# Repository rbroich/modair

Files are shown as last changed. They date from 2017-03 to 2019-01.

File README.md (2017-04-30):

# ModAir
Modular Aviation Instruments - Open Source Avionics for Microlights and other Non-Type-Certified Aircraft

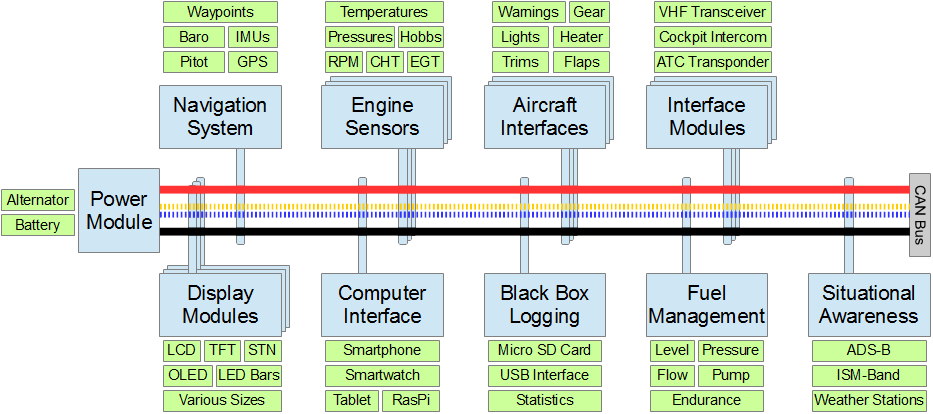
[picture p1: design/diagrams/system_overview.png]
System Overview


For documentation and details refer to the Hackaday.io Project Page [ModAir - Modular Aviation Instruments](https://hackaday.io/project/19325)

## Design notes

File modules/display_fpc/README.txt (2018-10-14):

ERC240160_ENCLOSURE

rotary encoder: solder ribbon cable
(mounted to PCB would have insufficient reach, and mechanically difficult to insert with the LCD FPC soldered on already)

add SPDT switch on left side
and LED?

Fine grid sand paper on top
Printed front panel labels on thick transparency (guerrilla glass?)
-black portions to cover 3d printed inconsistencies

PCB:
-no components on bottom side, besides BUS connector
-header for LCD backlight
-LCD FPC footprint directly below LCD, inline with edge of LCD frame
-header for rotary encoder
-solder pads for switch
-electrolytic caps mounted sideways

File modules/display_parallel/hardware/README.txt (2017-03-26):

Different Configurations:

Option 1: 5.8" WITSCHI_ERM25664AAG-1 EastRising 256x64 pixel graphic LCD module Blue backlight.
-LCD goes on top of PCB
-Headers row on the left aligns
-Mounting holes on the left align
-Top right mounting hole aligns with frame ground pad on LCD (solder spacer?)
-Electrolytic Caps C4 and C5 can be bent over
-Contrast Potentiometer not needed (already on LCD module)
-Rot Encoder header attached to Bottom
-LED (or header?) soldered on Bottom
-Screw Terminals attached to Bottom

Option 2: 2.9" NelyTech NT-G128641A 128x64 Graphic LCD Display Module 2xKS0108 Black on White.
-LCD goes on top of PCB
-Headers row on the bottom aligns
-All mounting holes align
-Bend electrolytic caps C4 and C5 over
-Contrast Potentiometer soldered
-Rot Encoder header attached to Bottom
-LED (or header?) soldered on Bottom
-Screw Terminals attached to Bottom

Option 3: 3.1" Generic 5V 12864B V2.0 LCD Display Module 128x64 Dots Graphic Matrix LCD Blue Backlight
-Identical mounting to Option 2
-CS1 becomes PSB [parallel mode] (ST7920, 2MHz clock rate)
-CS2 is not used
-Contrast Potentiometer not needed (already on LCD module)
-Backlight Resistor already on LCD module. Drive with 5V

Option 4: Generic HD44780 2x16 Character LCD Blue Backlight
-Cut PCB Smaller
-LCD goes on top of PCB, rotated 180 degrees
-Headers row on the bottom right aligns
-All mounting holes align
-Rot Encoder mounts vertically on top left PCB (isolate exposed header pins underneath...gnd plate on bottom of rotenc)
-LED mounts vertically on top right
-Electrolytic caps C4 and C5 mount vertically
-Screw Terminals attached to Bottom

ASSEMBLY:
Option 2 & 3:
-3D printed mounting hole standoffs with outer rectangle
-11mm Standoffs (distance between LCD and PCB)
-Male headers on LCD
-Female headers on PCB
-1.6mm PCBs

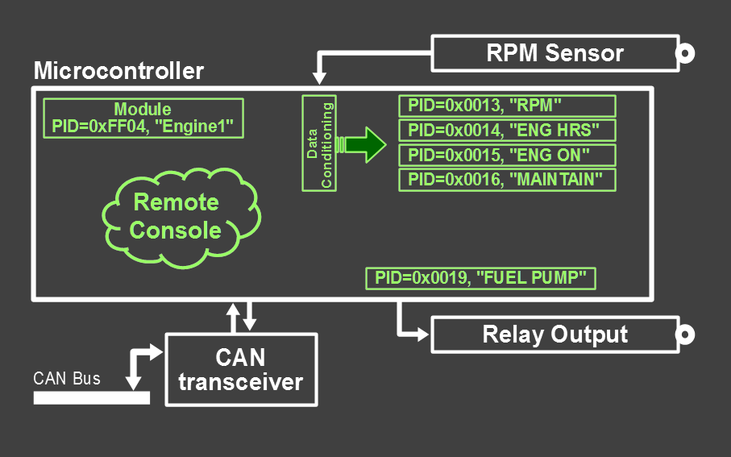
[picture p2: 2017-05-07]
design/diagrams/module_overview_white.png

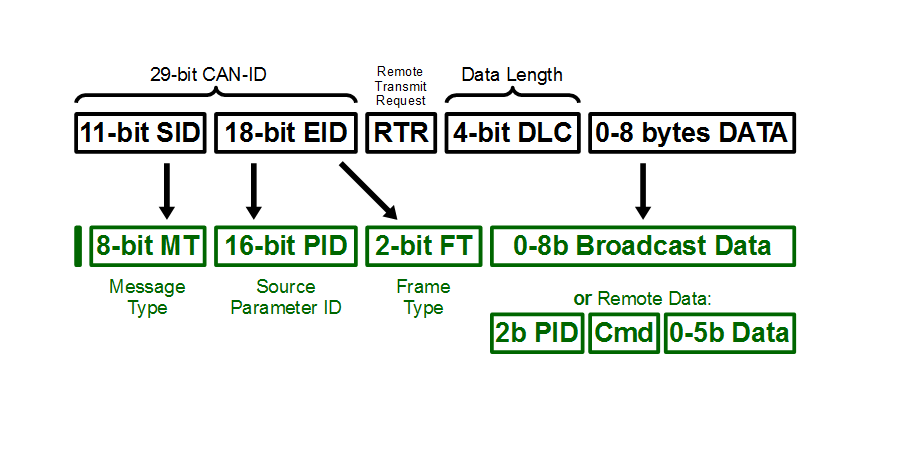
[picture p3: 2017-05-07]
design/diagrams/can_id_format_black.png

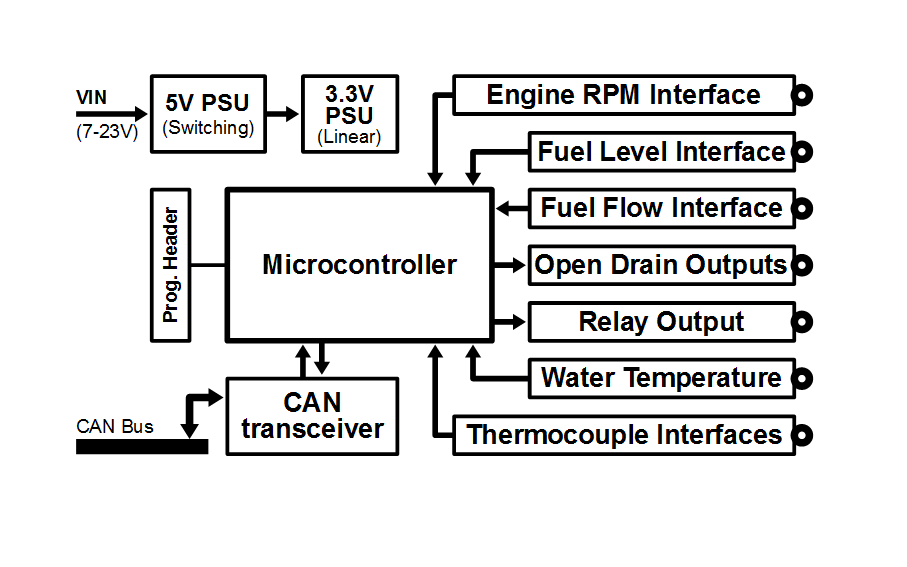
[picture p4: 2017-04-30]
design/diagrams/rotax_engine_module_black.png

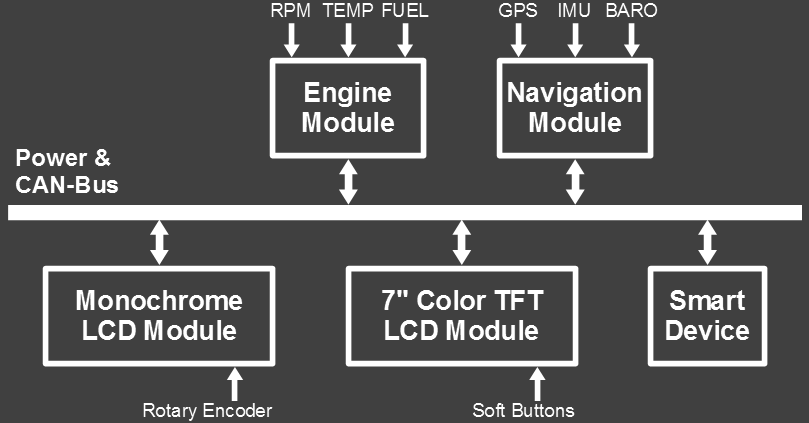
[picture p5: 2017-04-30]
design/diagrams/simple_block_diagram_white.png

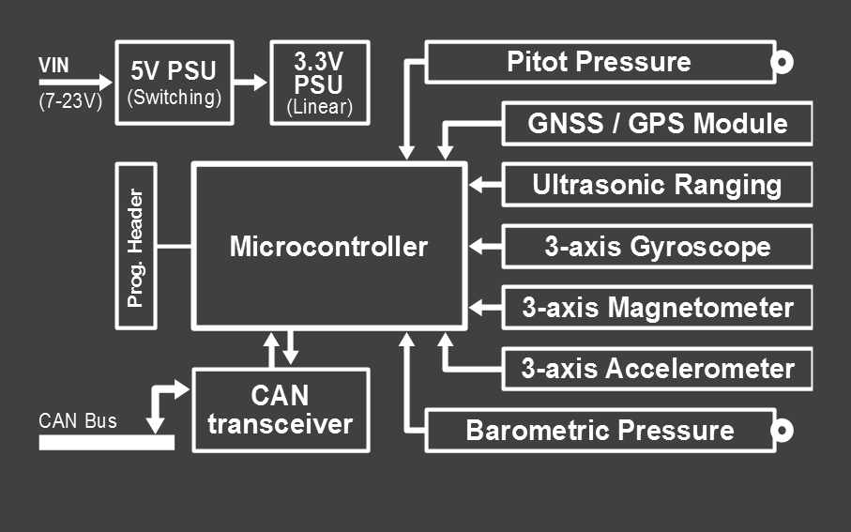
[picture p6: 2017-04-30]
design/diagrams/navigation_module_white.png

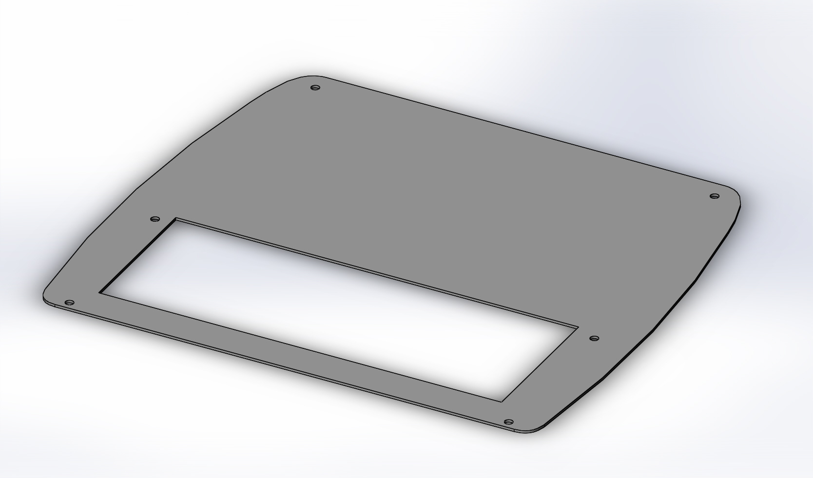
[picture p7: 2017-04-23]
modules/display_parallel/mechanical/solidworks_frontpanel/erm25664_frontpanel.JPG

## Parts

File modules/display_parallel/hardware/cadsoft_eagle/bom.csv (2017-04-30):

Qty | Value | Device | Package | Parts | Description | MF | MPN | OC_FARNELL | OC_NEWARK
1 |  | LED-FKIT-1206 | FKIT-LED-1206 | PWR | LEDs
1 |  | LED5MM | LED5MM | LED1 | LED
1 |  | M05PTH | 1X05 | JP1 | Header 5
1 |  | MA04-1 | MA04-1 | ROT_ENC | PIN HEADER |  |  | unknown | unknown
2 |  | MOSFET-NREFLOW | SOT23 | Q1, Q3 | N-Channel Mosfet
1 |  | TRIM_EU-B64Y | B64Y | R1 | POTENTIOMETER
1 | 0R-JUMPB | 0R-JUMPB | B0R-JMP | JMP1 | SMD 0R 0805 Jumper
2 | 100n | C-EUC0603K | C0603K | C6, C7 | CAPACITOR, European symbol
1 | 100u | CPOL-EUE2.5-7 | E2,5-7 | C4 | POLARIZED CAPACITOR, European symbol
3 | 10k | R-EU_R0603 | R0603 | R7, R11, R16 | RESISTOR, European symbol
1 | 10u | C-EU025-030X050 | C025-030X050 | C10 | CAPACITOR, European symbol
1 | 120 | R-EU_R0603 | R0603 | R21 | RESISTOR, European symbol
3 | 150 | R-EU_R0603 | R0603 | R2, R3, R4 | RESISTOR, European symbol
1 | 1N4004 | 1N4004 | DO41-10 | D1 | DIODE
4 | 1u | C-EUC0603K | C0603K | C1, C2, C3, C9 | CAPACITOR, European symbol
3 | 33n | C-EUC0603K | C0603K | C11, C12, C13 | CAPACITOR, European symbol
1 | 470u | CPOL-EUE3.5-8 | E3,5-8 | C5 | POLARIZED CAPACITOR, European symbol
1 | AMS1117 | LD117AS33TR | SOT223 | IC5 | Low drop fixed and adjustable positive voltage regulators 1 A
1 | DSPIC33EP512GP502-I/SP | DSPIC33EP512GP502-I/SP | DIL28-3 | IC1 | 16-Bit Microcontrollers and Digital Signal Controllers
1 | EASTRISING_12864-2 | EASTRISING_12864-2 | 1X20 | G12864 | 2.9128x64 Graphic LCD Display Module KS0108 Black on White."
1 | F/QMX | F/QMX | F/QMX | BUZZ | BUZZER Source: Buerklin |  |  | unknown | unknown
1 | GENERIC_16X02_LCD | GENERIC_16X02_LCD | 1X16 | C1602
1 | MCP2562 | MCP2562-E/P | DIL8 | IC3 | High-Speed CAN Transceiver
1 | MINI_DC_DC_CONVSMD | MINI_DC_DC_CONVSMD | DSN-MINI-360-SMD | U$1 | RC Airplane Module Mini 360 DC Buck Converter Step Down Module 4.75V-23V to 1V-17V 17x11x3.8mm New LM2596;
1 | ROTARTY_ENCODER | ROTARTY_ENCODER | ROTARY_ENC_PLAIN | SW1 | Simple no LED rotary encoder
1 | WITSCHI_ERM25664AAG-1 | WITSCHI_ERM25664AAG-1 | 1X20 | GLCD_ERM | EastRising 256x64 pixel graphic LCD module
2 | XY301V-A | XY301V-A | XY301V-A | CN1, CN2 | 3 Pin Screw Terminal Block Connector 5mm Pitch 5.08-301-3P 301-3P 3pin

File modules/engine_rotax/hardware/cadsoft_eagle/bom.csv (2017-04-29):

Qty | Value | Device | Package | Parts | Description | MF | MPN | OC_FARNELL | OC_NEWARK | PROD_ID | VALUE
1 |  | DIODESMA | SMADIODE | D1 | Diode
2 |  | LED-FKIT-1206 | FKIT-LED-1206 | 3.3V_PWR, LED | LEDs
5 |  | M01PTH_LONGPAD | 1X01_LONGPAD | COM, NC, NO, OD1, OD2 | Header 1
1 |  | M05PTH | 1X05 | JP1 | Header 5
1 |  | MOSFET-NREFLOW | SOT23 | Q1 | N-Channel Mosfet
1 | 1000u | CPOL-EUE3.5-8 | E3,5-8 | C5 | POLARIZED CAPACITOR, European symbol
1 | 100k | R-EU_R0603 | R0603 | R18 | RESISTOR, European symbol
2 | 100n | C-EUC0603K | C0603K | C4, C7 | CAPACITOR, European symbol
1 | 100u | CPOL-EUE2.5-7 | E2,5-7 | C3 | POLARIZED CAPACITOR, European symbol
1 | 10k | R-EU_R0603 | R0603 | R11 | RESISTOR, European symbol
1 | 10u | C-EUC3225 | C3225 | C6 | CAPACITOR, European symbol
2 | 120 | R-EU_R0603 | R0603 | R9, R21 | RESISTOR, European symbol
2 | 150 | R-EU_R0603 | R0603 | R1, R4 | RESISTOR, European symbol
8 | 1k | R-EU_R0603 | R0603 | R3, R7, R8, R10, R12, R13, R14, R17 | RESISTOR, European symbol
1 | 1k5 | R-EU_R0603 | R0603 | R6 | RESISTOR, European symbol
1 | 1u | C-EUC0603 | C0603 | C9 | CAPACITOR, European symbol
2 | 1u | C-EUC0603K | C0603K | C1, C2 | CAPACITOR, European symbol
1 | 200k | R-EU_R0603 | R0603 | R19 | RESISTOR, European symbol
2 | 22k | R-EU_R0603 | R0603 | R2, R5 | RESISTOR, European symbol
1 | 2n7002 | MOSFET-NREFLOW | SOT23 | Q3 | N-Channel Mosfet
1 | AMS1117-3.3 | LD117AS33TR | SOT223 | IC5 | Low drop fixed and adjustable positive voltage regulators 1 A
1 | DSPIC33EP32GP502-I/SO | DSPIC33EP32GP502-I/SO | SO28W | IC2 | 16-Bit Microcontrollers and Digital Signal Controllers
1 | IRF540N | MOSFET-NGDS_TO220V | TO220V | Q2 | N-Channel Mosfet
1 | JQC-3FF-12 | G5L | G5LE | K1 | RELAY |  |  | unknown | unknown
8 | LSP10 | LSP10 | LSP10 | 0V, 3.3V, 5.0V, GND, IO1, IO2, IO3, IO4 | SOLDER PAD drill 1.0 mm, distributor Buerklin, 12H555
2 | MAX6675 | MAX6675 | SO08 | IC1, IC4 | Cold-Junction-Compensated K-Thermocouple-to-Digital Converter
1 | MCP2562-E/P | MCP2562-E/P | DIL8 | IC3 | High-Speed CAN Transceiver
1 | MINI_DC_DC_CONVSMD | MINI_DC_DC_CONVSMD | DSN-MINI-360-SMD | U$1 | RC Airplane Module Mini 360 DC Buck Converter Step Down Module 4.75V-23V to 1V-17V 17x11x3.8mm New LM2596;
13 | N/A | R-EU_R0603 | R0603 | R15, R16, R20, R23, R24, R25, R26, R29, R30, R31, R32, R35, R36 | RESISTOR, European symbol
2 | PMEG4005EJ | DIODE-SCHOTTKY-PMEG4005EJ | SOD-323 | D2, D5 | Schottky diodes in SFE's production catalog |  |  |  |  | DIO-10955 | PMEG4005EJ
4 | XY301V-A | XY301V-A | XY301V-A | CN1, CN2, CN3, CN4 | 3 Pin Screw Terminal Block Connector 5mm Pitch 5.08-301-3P 301-3P 3pin
1 | Zener 3.3V | DIODE-ZENERMM | MINIMELF | Z2 | Zener Diode

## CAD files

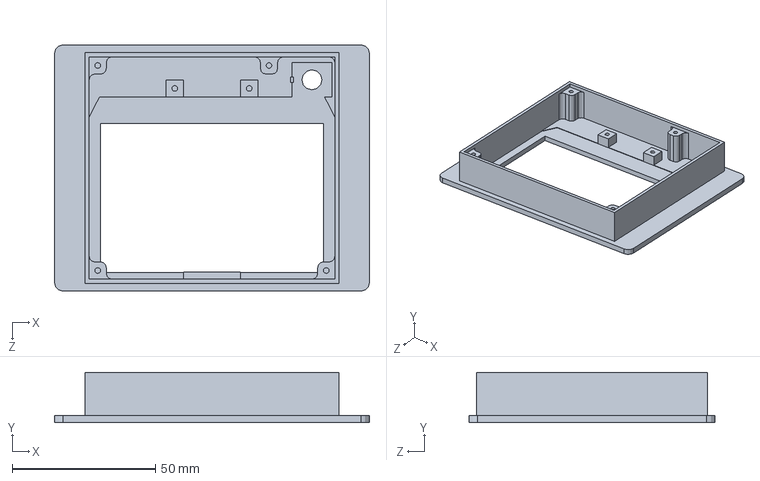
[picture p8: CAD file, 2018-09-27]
modules/display_fpc/mechanical/solidworks_enclosure/ERC240160_ENCLOSURE.SLDPRT
110.0 x 17.5 x 86.0 mm

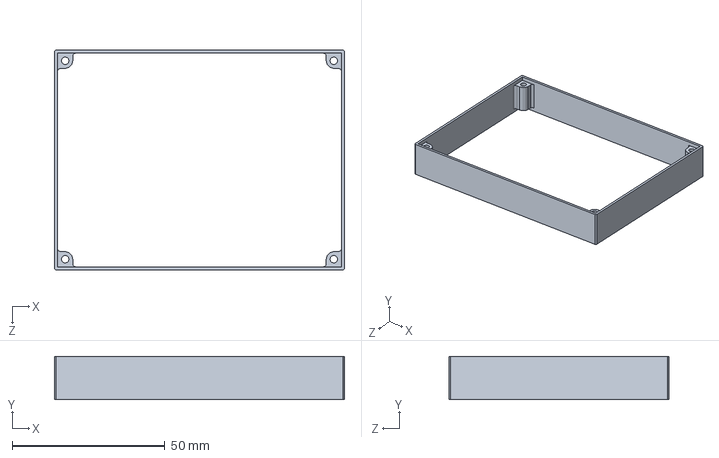
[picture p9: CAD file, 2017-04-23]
modules/display_parallel/mechanical/solidworks_brackets/g12864b_bracket.SLDPRT
95.0 x 14.2 x 72.0 mm

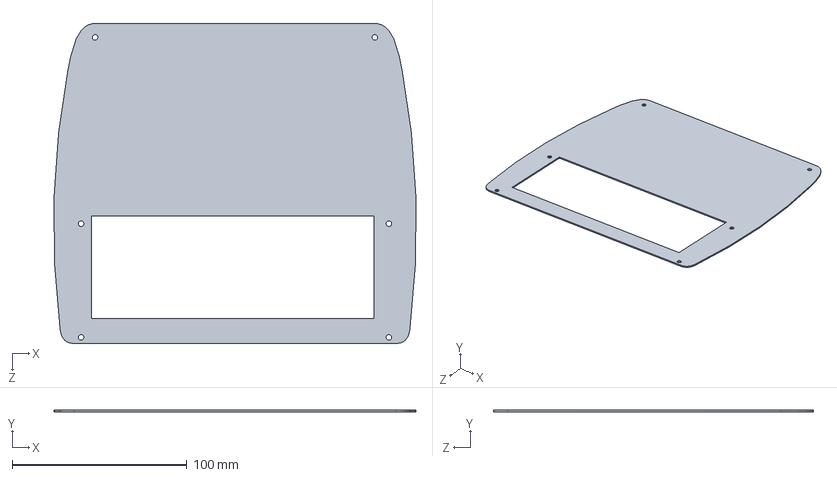
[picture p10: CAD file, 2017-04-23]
modules/display_parallel/mechanical/solidworks_frontpanel/erm25664_frontpanel.SLDPRT
207.0 x 1.00 x 183.0 mm

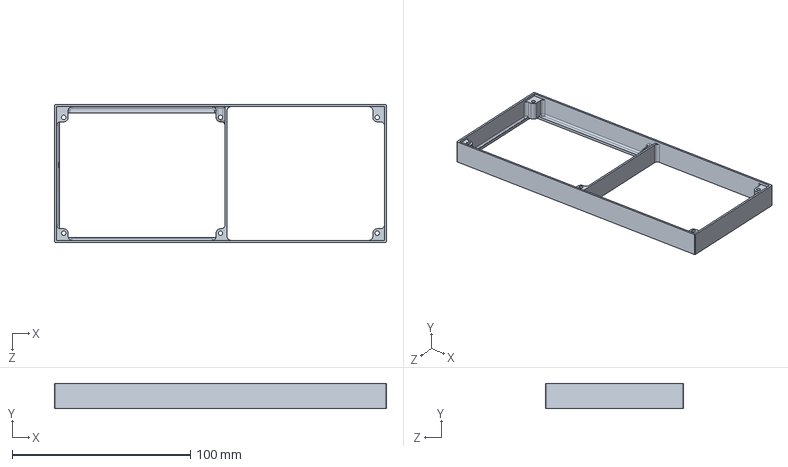
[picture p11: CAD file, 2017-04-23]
modules/display_parallel/mechanical/solidworks_brackets/erm25664_bracket.SLDPRT
186.4 x 14.2 x 77.4 mm

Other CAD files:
modules/display_fpc/mechanical/solidworks_enclosure/ERC240160_ENCLOSURE.SLDDRW
modules/display_fpc/mechanical/solidworks_enclosure/ERC240160_ENCLOSURE.STL
modules/display_parallel/mechanical/solidworks_brackets/erm25664_bracket.STL
modules/display_parallel/mechanical/solidworks_brackets/g12864b_bracket.STL
modules/display_parallel/mechanical/solidworks_frontpanel/erm25664_frontpanel.DXF

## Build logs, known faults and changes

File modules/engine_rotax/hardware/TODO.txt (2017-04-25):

change CAN transceiver to SMD

cable mounting? move screw terminals closer to edge of box, and shorten PCB on that side.
Ensure no THP and ideally no top-layer routes between screw terminal and edge of PCB. Add holes for cable tie to hold down cables?

add capacitor from RPM_IRQ to GND?

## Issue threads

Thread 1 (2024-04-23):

The status of the project is developing | abandoned

brightproject, 2024-04-23:
Good afternoon @rbroich
Your project is interesting, are you still developing it?
How are things going with the ACRS? Have you tried it in real flights?
If you are interested, you can chat.

rbroich, 2024-04-23:
Hello,
Thank you for your interest in this project. Yes, I actively used it for quite a while until I sold the plane and moved to another country. Unfortunately this also means that the project is abandoned now. You can find a write-up of the concepts on hackaday.
Kind regards

brightproject, 2024-04-23:
> Hello, Thank you for your interest in this project. Yes, I actively used it for quite a while until I sold the plane and moved to another country. Unfortunately this also means that the project is abandoned now. You can find a write-up of the concepts on hackaday. Kind regards

Yes, I read the concept on `hackaday`.
From the code in the repository * I didn’t quite understand, did you get the orientation angles (roll, heading and yaw) from the `MEMS` gyroscope and accelerometer sensor?
As I understand it, the navigation module received data from `MEMS` sensors and transmitted them via the `CAN` bus to another microcontroller, which in turn displayed attitude indicator information on the display.

> https://github.com/rbroich/modair/blob/master/modules/display_parallel/firmware/dspic_ntg128641a/widgets.c

Or your device did not display a picture of the attitude indicator, but only this data:
```
        // compass with GPS heading
        draw_compass(31,31,pid_vals[17].val);

        // fuel level: text
        LCD_string((char*)"Fuel ", 0, 117, font_sml2);
        ptr = mprint_float(tmp_str, pid_vals[7].val, 2, 2); // 48.63l
        strcpy(ptr,"l");
        LCD_string(tmp_str, LCD_X-6*4, 117, font_sml2);

        // fuel level: bottom hbar
        draw_hbar(0,123,64,5,pid_vals[7].val*100.0/50.0);

        // bus voltage: bottom right
        ptr = mprint_float(tmp_str, pid_vals[0].val, 2, 1); // xx.xV
        strcpy(ptr,"V");
        LCD_string(tmp_str, 0, 111, font_sml2);

        // h20 temp: bottom left (1 line up)
        ptr = mprint_float(tmp_str, pid_vals[8].val, 2, 1); // xx.x
        strcpy(ptr," C");
        LCD_string(tmp_str, LCD_X-24, 110, font_sml2);
        lcd_setpixel(LCD_X-6,110,LCD_BLACK); // degrees dot

        // Altitude
        ptr = mprint_float(tmp_str, pid_vals[19].val, 4, 0); // 5560 ft
        strcpy(ptr," ft");
        LCD_string(tmp_str, 32-3.5*6, 65, font_def);

        // Velocity
        ptr = mprint_float(tmp_str, pid_vals[18].val, 2, 0); // 54 mph
        strcpy(ptr," mph");
        LCD_string(tmp_str, 32-3*6, 65+9, font_def);

        // RPM
        ptr = mprint_float(tmp_str, pid_vals[3].val, 4, 0); // 2240 rpm
        strcpy(ptr," RPM");
        LCD_string(tmp_str, 31-4*4, 88, font_sml1);
        LCD_line(4,95,LCD_X-1-4,95,LCD_BLACK);
        u8 rpm_ratio = pid_vals[3].val*(LCD_X-8)/8000.0;
        LCD_line(4+rpm_ratio,97,4+rpm_ratio,94,LCD_BLACK);
        LCD_line(3+rpm_ratio,97,3+rpm_ratio,94,LCD_BLACK);

        // engine on time: bottom left (2 lines up)
        ptr = mprint_float(tmp_str, pid_vals[5].val*60.0, 3, 0); // 012m
        strcpy(ptr,"m");
        LCD_string(tmp_str, 0, 104, font_sml2);

        // Time in UTC
        u8 *fl_ptr;
        fl_ptr = (u8*)&pid_vals[20].val;
        ptr = mprint_int(tmp_str, fl_ptr[2], 10, 2); // 06:54
        *ptr++ = ':';
        mprint_int(ptr, fl_ptr[1], 10, 2);
        LCD_string(tmp_str, LCD_X-5*4, 104, GLCD_ROTATE_0,GLCD_FONT_3x5,LCD_BLACK,5);
```
Why was MPU6050 used in the project?

> https://github.com/rbroich/modair/blob/d1b8abdae54bf87aca975da74885fdfdacb7dc6f/modules/navigation/firmware/dspic_nav/mpu6050_driv.c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

Do you have any photos of the display with the menu and in operation?
I'm interested in understanding your code and rewriting it for `STM32` for a color display.

brightproject, 2024-12-02:
Good day @rbroich 🙂
Unfortunately, you don't answer often, apparently you have little time for your hobby and this project.
I would like to ask you one more question, in this project

> https://hackaday.io/project/21327-modair-navigation-module

you indicated that it is possible to implement the following Features in the module:

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

When studying the code, I did not find a block for determining the vertical speed.
Could you tell me how you implemented or not the measurement of `vertical speed`?

You also wrote that you plan to return to the project, I would be interested in your return, because I am curious about your implementation of the exchange protocol based on the `CAN` bus. However, I do not quite understand its implementation and why you did not start using generally accepted `CAN ID` numbers, such as, for example, the `ARINC 825` standard for `CANaerospace`?

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

[can_as.zip](https://github.com/user-attachments/files/17982959/can_as.zip)

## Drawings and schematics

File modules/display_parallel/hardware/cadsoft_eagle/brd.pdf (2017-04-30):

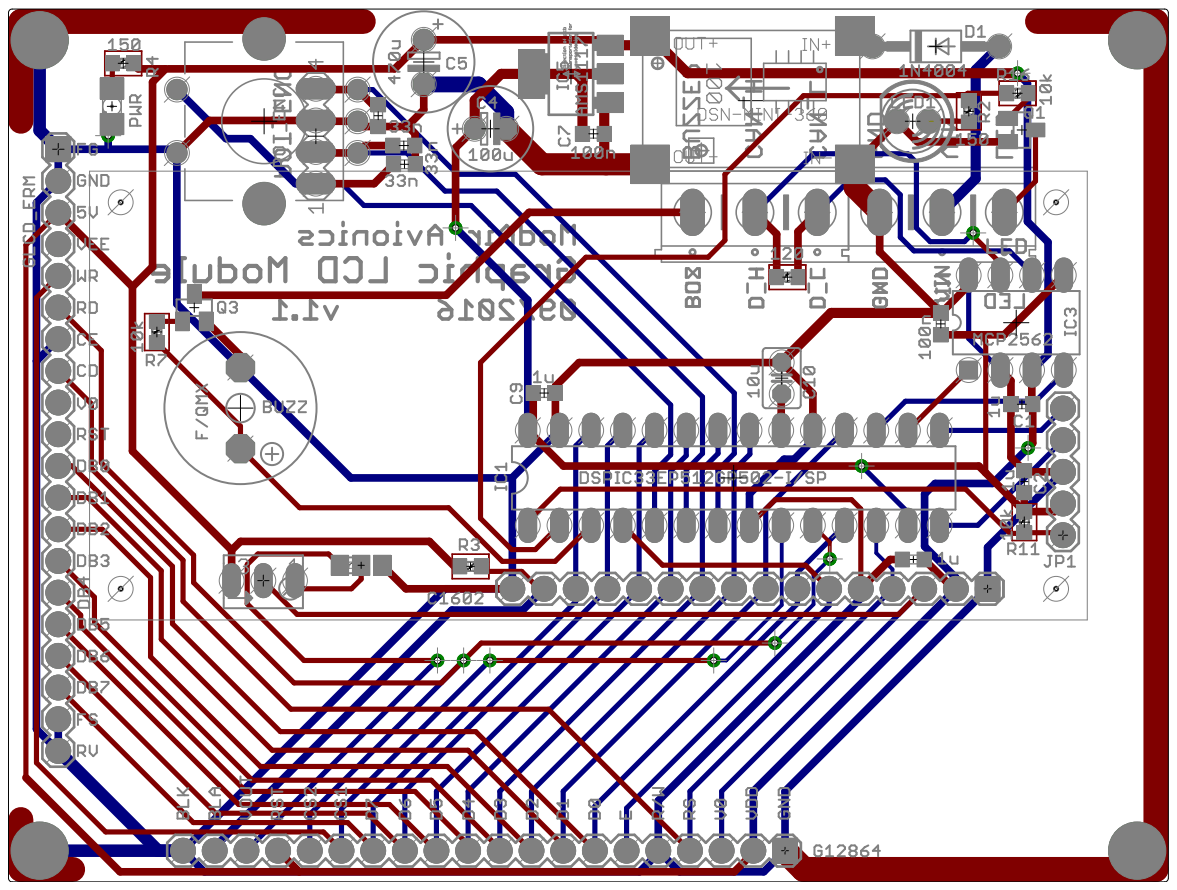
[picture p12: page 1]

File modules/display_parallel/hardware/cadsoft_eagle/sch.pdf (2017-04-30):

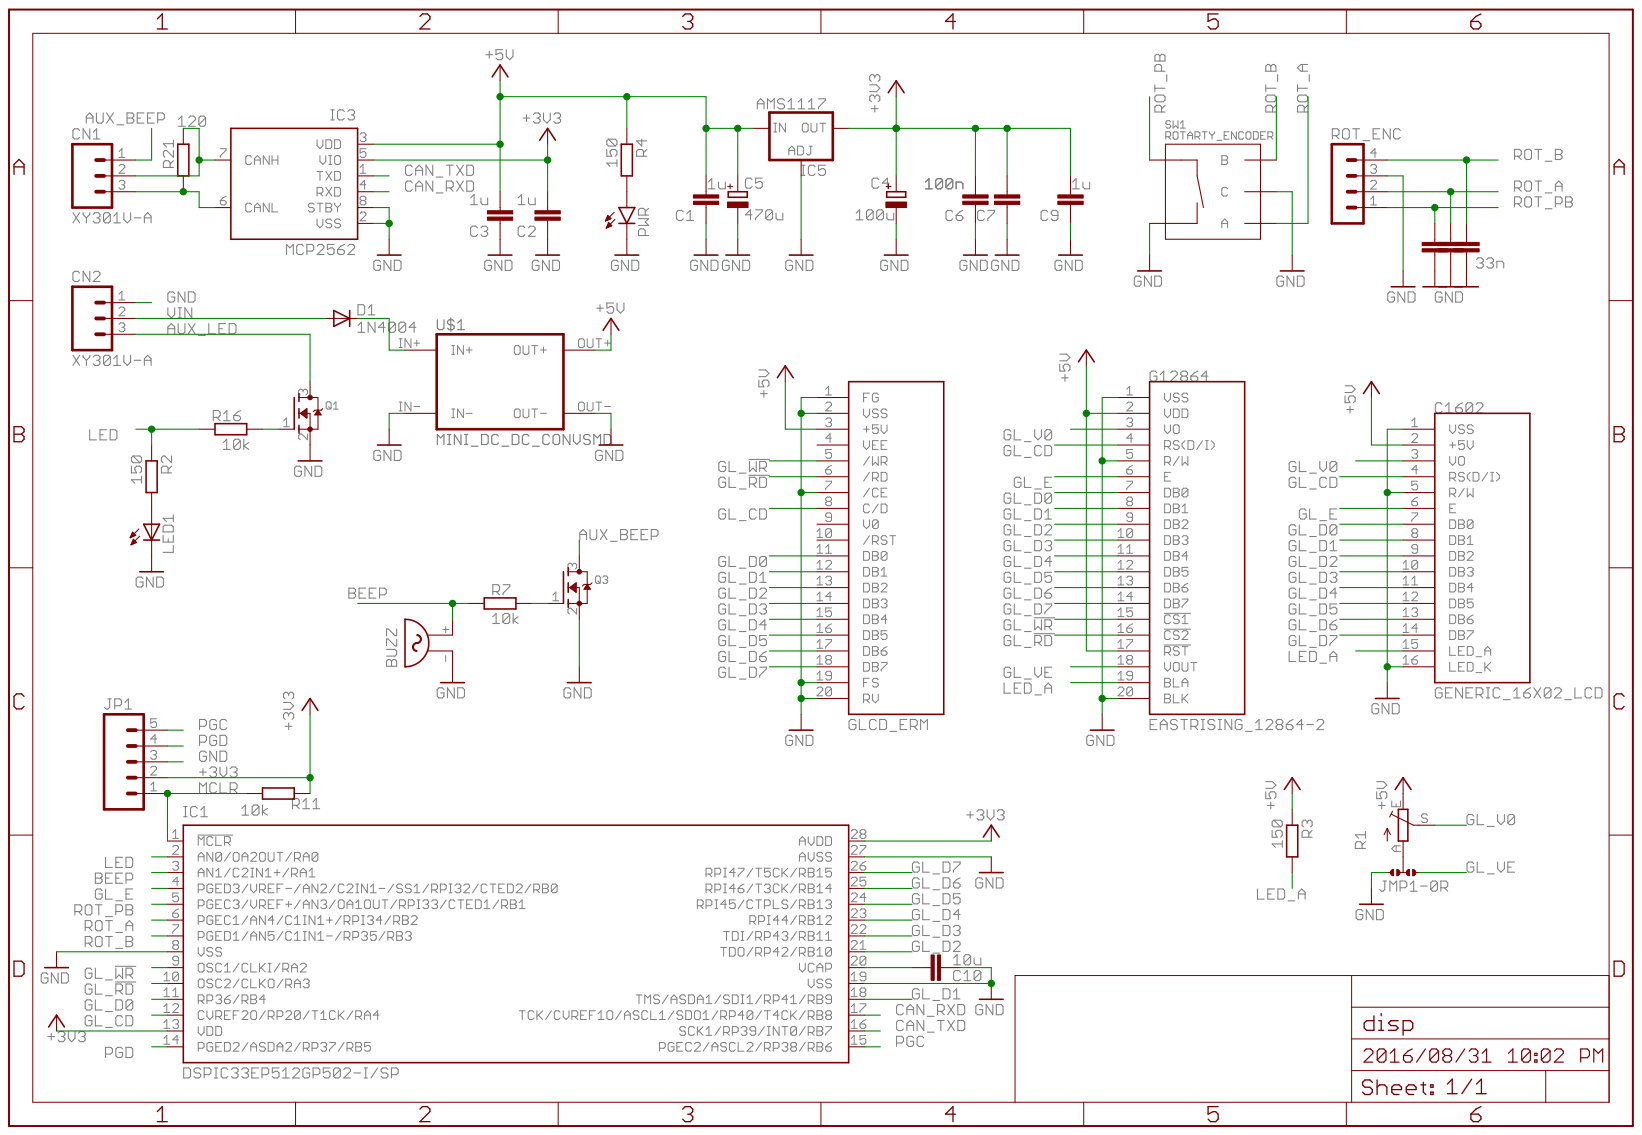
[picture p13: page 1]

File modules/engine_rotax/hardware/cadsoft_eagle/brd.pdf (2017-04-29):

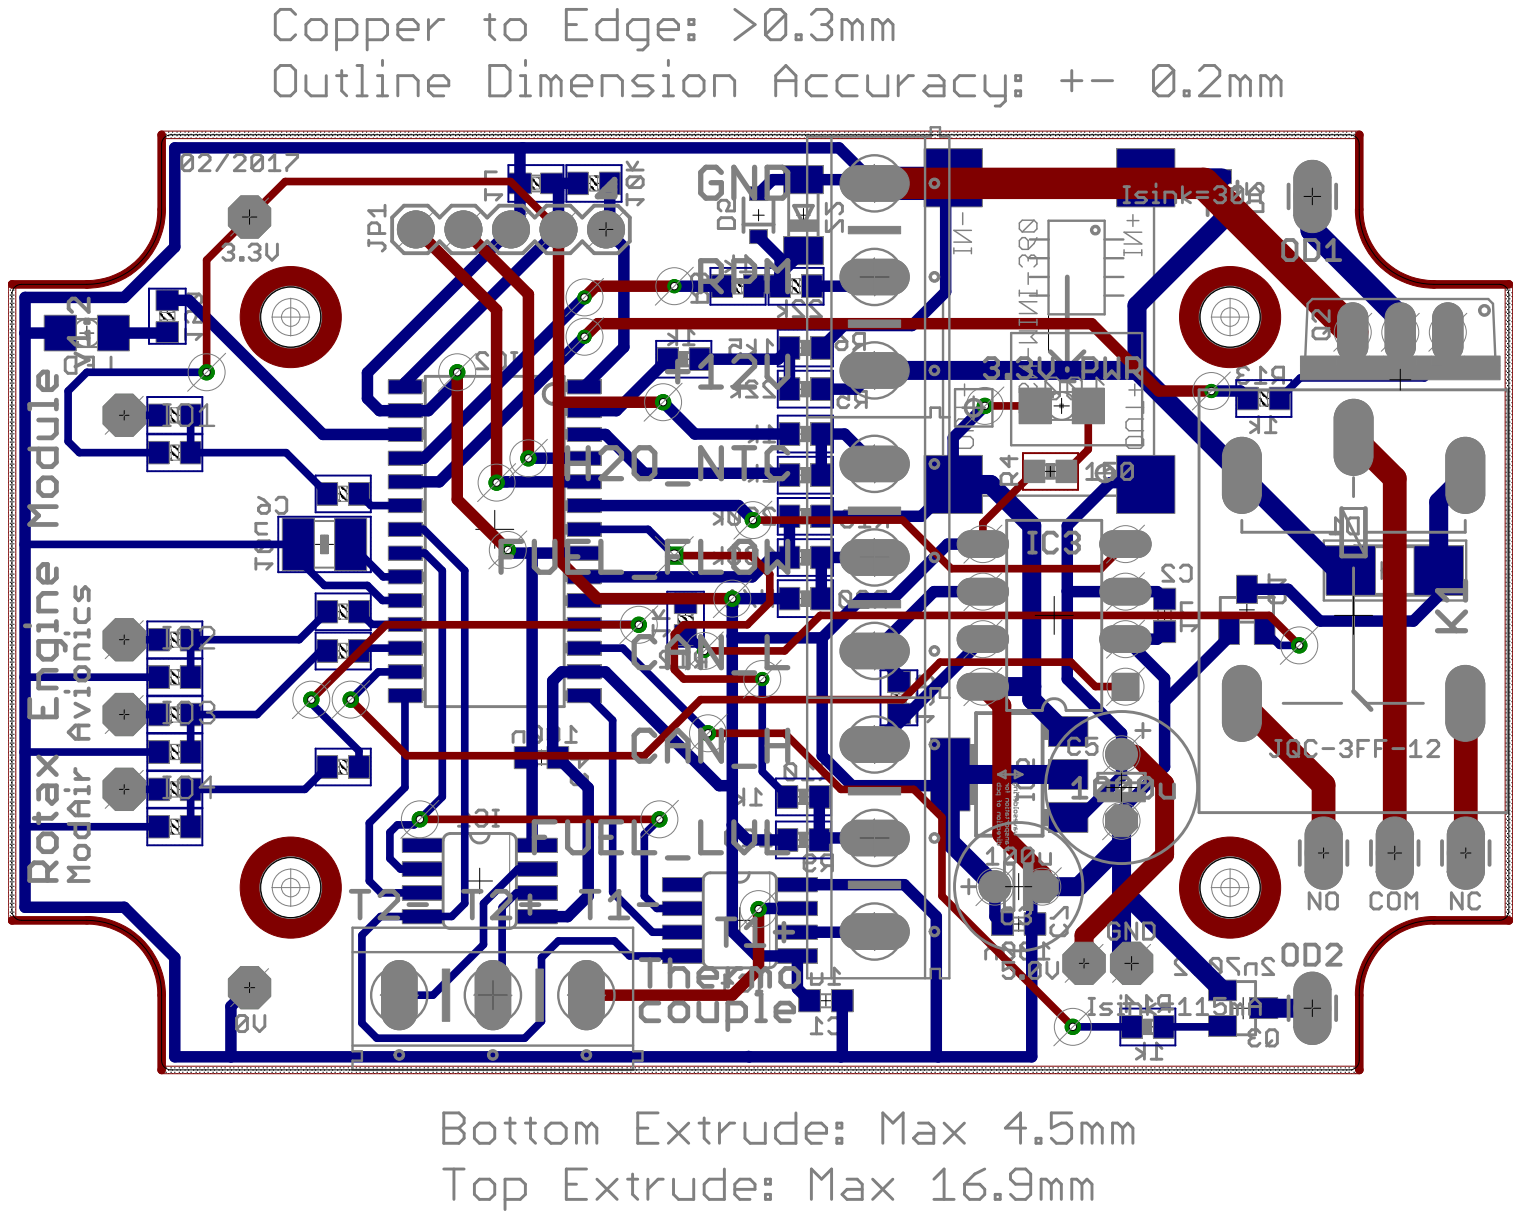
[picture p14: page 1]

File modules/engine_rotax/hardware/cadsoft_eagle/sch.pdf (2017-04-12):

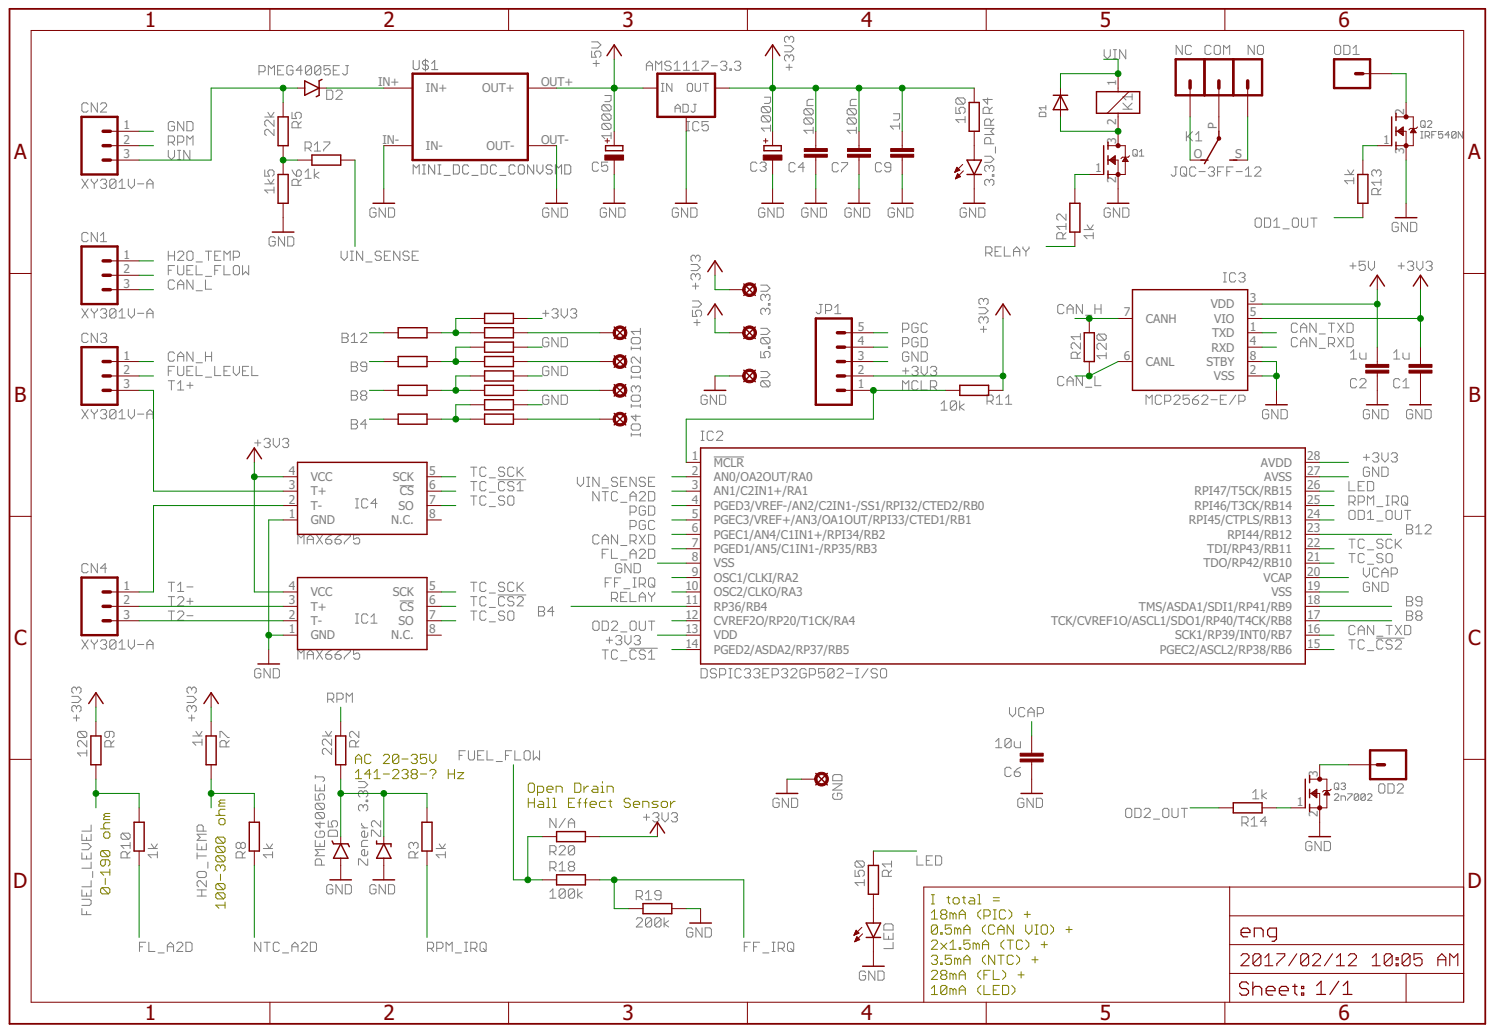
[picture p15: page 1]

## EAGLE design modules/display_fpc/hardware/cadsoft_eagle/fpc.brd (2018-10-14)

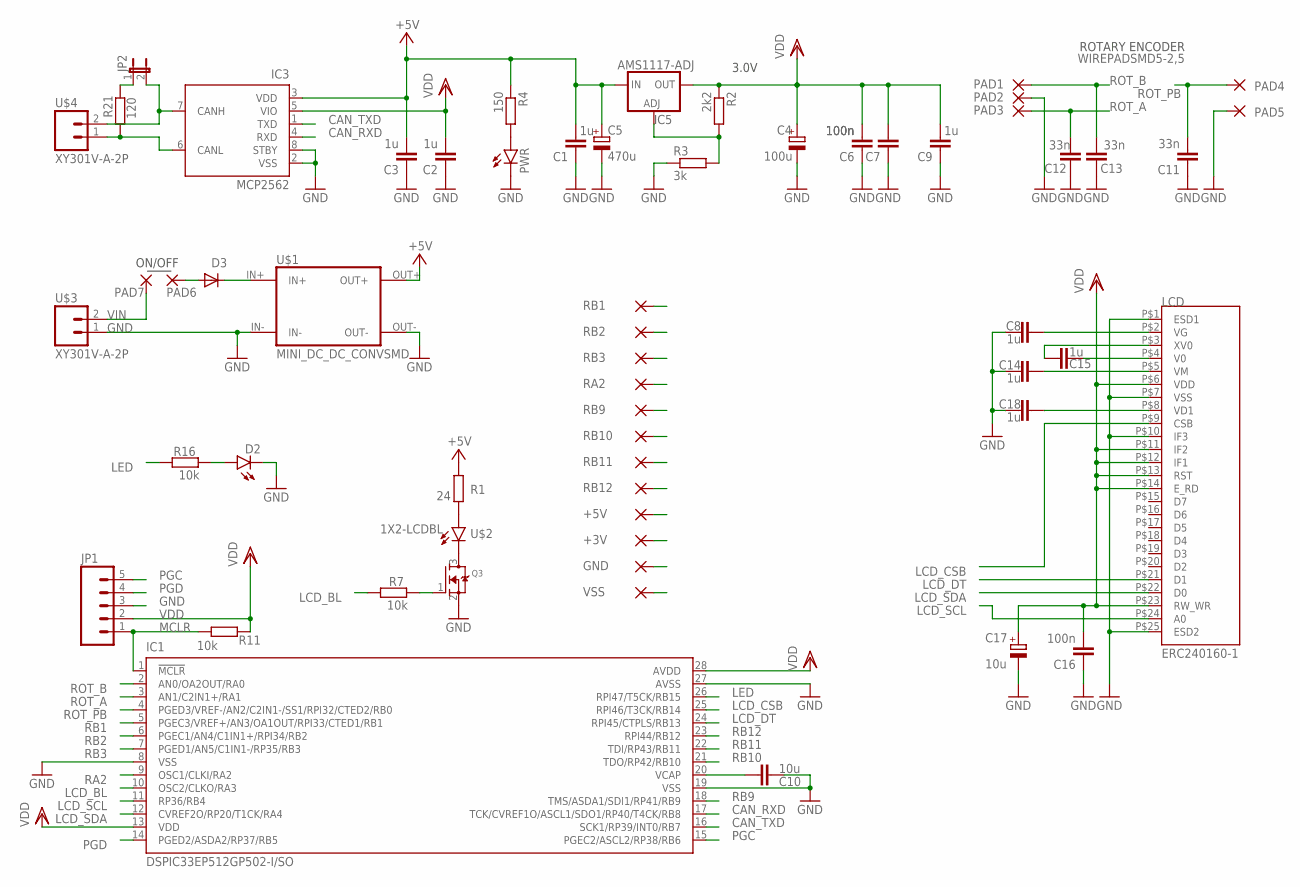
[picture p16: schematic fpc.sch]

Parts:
+3V, +5V: WIREPADSMD1,27-254; SMD1,27-2,54
C1, C2, C3, C8, C9, C14, C15, C18: 1u; C0603K
C4: 100u; SANYO-OSCON_SMD_B6
C5: 470u; SANYO-OSCON_SMD_B6
C6, C7, C16: 100n; C0603K
C10: 10u; C0805
C11, C12, C13: 33n; C0603K
C17: 10u; SANYO-OSCON_SMD_E12
D2: LED-FKIT-1206; FKIT-LED-1206
D3: DIODESMA; SMADIODE
GND: WIREPADSMD1,27-254; SMD1,27-2,54
IC1: DSPIC33EP512GP502-I/SO; SO28W
IC3: MCP2562; SO-08
IC5: AMS1117-ADJ; SOT223
JP1: M05PTH; 1X05
JP2: JP1E; JP1
LCD: ERC240160-1; 1X25-LCDFPC-SMD
PAD1, PAD2, PAD3, PAD4, PAD5, PAD6, PAD7: WIREPADSMD5-2,5; 5-2,5
PWR: LED-FKIT-1206; FKIT-LED-1206
Q3: MOSFET-NREFLOW; SOT23
R1: 24; R0805
R2: 2k2; R0603
R3: 3k; R0603
R4: 150; R0603
R7, R11, R16: 10k; R0603
R21: 120; R0603
RA2: WIREPADSMD1,27-254; SMD1,27-2,54
RB1, RB2, RB3, RB9, RB10, RB11, RB12: WIREPADSMD1,27-254; SMD1,27-2,54
U$1: MINI_DC_DC_CONVSMD; DSN-MINI-360-SMD
U$2: 1X2-LCDBL; 1X2-LCDBL-SMD
U$3, U$4: XY301V-A-2P
VSS: WIREPADSMD1,27-254; SMD1,27-2,54

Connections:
+5V: +5V.1, C1.2, C3.2, C5.+, IC3.3 (VDD), IC5.3 (IN), R1.1, R4.1, U$1.OUT+
CAN_H: IC3.7 (CANH), JP2.2, U$4.2
CAN_L: IC3.6 (CANL), R21.1, U$4.1
CAN_RXD: IC1.17 (TCK/CVREF1O/ASCL1/SDO1/RP40/T4CK/RB8), IC3.4 (RXD)
CAN_TXD: IC1.16 (SCK1/RP39/INT0/RB7), IC3.1 (TXD)
GND: C1.1, C2.1, C3.1, C4.-, C5.-, C6.1, C7.1, C8.1, C9.1, C10.1, C11.1, C12.1, C13.1, C14.1, C16.1, C17.-, C18.1, D2.C, GND.1, IC1.8 (VSS), IC1.19 (VSS), IC1.27 (AVSS), IC3.2 (VSS), IC3.8 (STBY), JP1.3, LCD.P$1 (ESD1), LCD.P$7 (VSS), LCD.P$10 (IF3), LCD.P$25 (ESD2), PAD2.1, PAD5.1, PWR.C, Q3.2 (S), R3.1, U$1.IN-, U$1.OUT-, U$3.1, VSS.1
LCD_BL: IC1.10 (OSC2/CLKO/RA3), R7.2
LCD_CSB: IC1.25 (RPI46/T3CK/RB14), LCD.P$9 (CSB)
LCD_DT: IC1.24 (RPI45/CTPLS/RB13), LCD.P$21 (D1)
LCD_SCL: IC1.11 (RP36/RB4), LCD.P$24 (A0)
LCD_SDA: IC1.12 (CVREF2O/RP20/T1CK/RA4), LCD.P$22 (D0)
LED: IC1.26 (RPI47/T5CK/RB15), R16.2
MCLR: IC1.1 (!MCLR!), JP1.1, R11.2
unnamed: Q3.1 (G), R7.1
unnamed: R1.2, U$2.A
unnamed: PWR.A, R4.2
unnamed: Q3.3 (D), U$2.K (C)
unnamed: C15.2, LCD.P$4 (V0)
unnamed: C15.1, LCD.P$3 (XV0)
unnamed: C8.2, LCD.P$2 (VG)
unnamed: C14.2, LCD.P$5 (VM)
unnamed: D2.A, R16.1
unnamed: C18.2, LCD.P$8 (VD1)
unnamed: IC5.1 (ADJ), R2.2, R3.2
unnamed: D3.A, PAD6.1
unnamed: JP2.1, R21.2
PGC: IC1.15 (PGEC2/ASCL2/RP38/RB6), JP1.5
PGD: IC1.14 (PGED2/ASDA2/RP37/RB5), JP1.4
RA2: IC1.9 (OSC1/CLKI/RA2), RA2.1
RB1: IC1.5 (PGEC3/VREF+/AN3/OA1OUT/RPI33/CTED1/RB1), RB1.1
RB2: IC1.6 (PGEC1/AN4/C1IN1+/RPI34/RB2), RB2.1
RB3: IC1.7 (PGED1/AN5/C1IN1-/RP35/RB3), RB3.1
RB9: IC1.18 (TMS/ASDA1/SDI1/RP41/RB9), RB9.1
RB10: IC1.21 (TDO/RP42/RB10), RB10.1
RB11: IC1.22 (TDI/RP43/RB11), RB11.1
RB12: IC1.23 (RPI44/RB12), RB12.1
ROT_A: C12.2, IC1.3 (AN1/C2IN1+/RA1), PAD3.1
ROT_B: C13.2, IC1.2 (AN0/OA2OUT/RA0), PAD1.1
ROT_PB: C11.2, IC1.4 (PGED3/VREF-/AN2/C2IN1-/SS1/RPI32/CTED2/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), PAD4.1
VCAP: C10.2, IC1.20 (VCAP)
VDD: +3V.1, C2.2, C4.+, C6.2, C7.2, C9.2, C16.2, C17.+, IC1.13 (VDD), IC1.28 (AVDD), IC3.5 (VIO), IC5.2 (OUT), IC5.@2 (OUT), JP1.2, LCD.P$6 (VDD), LCD.P$11 (IF2), LCD.P$12 (IF1), LCD.P$13 (RST), LCD.P$14 (E_RD), LCD.P$23 (RW_WR), R2.1, R11.1
VIN: PAD7.1, U$3.2
VIN_D: D3.C, U$1.IN+

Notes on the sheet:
3.0V
ON/OFF
ROTARY ENCODER

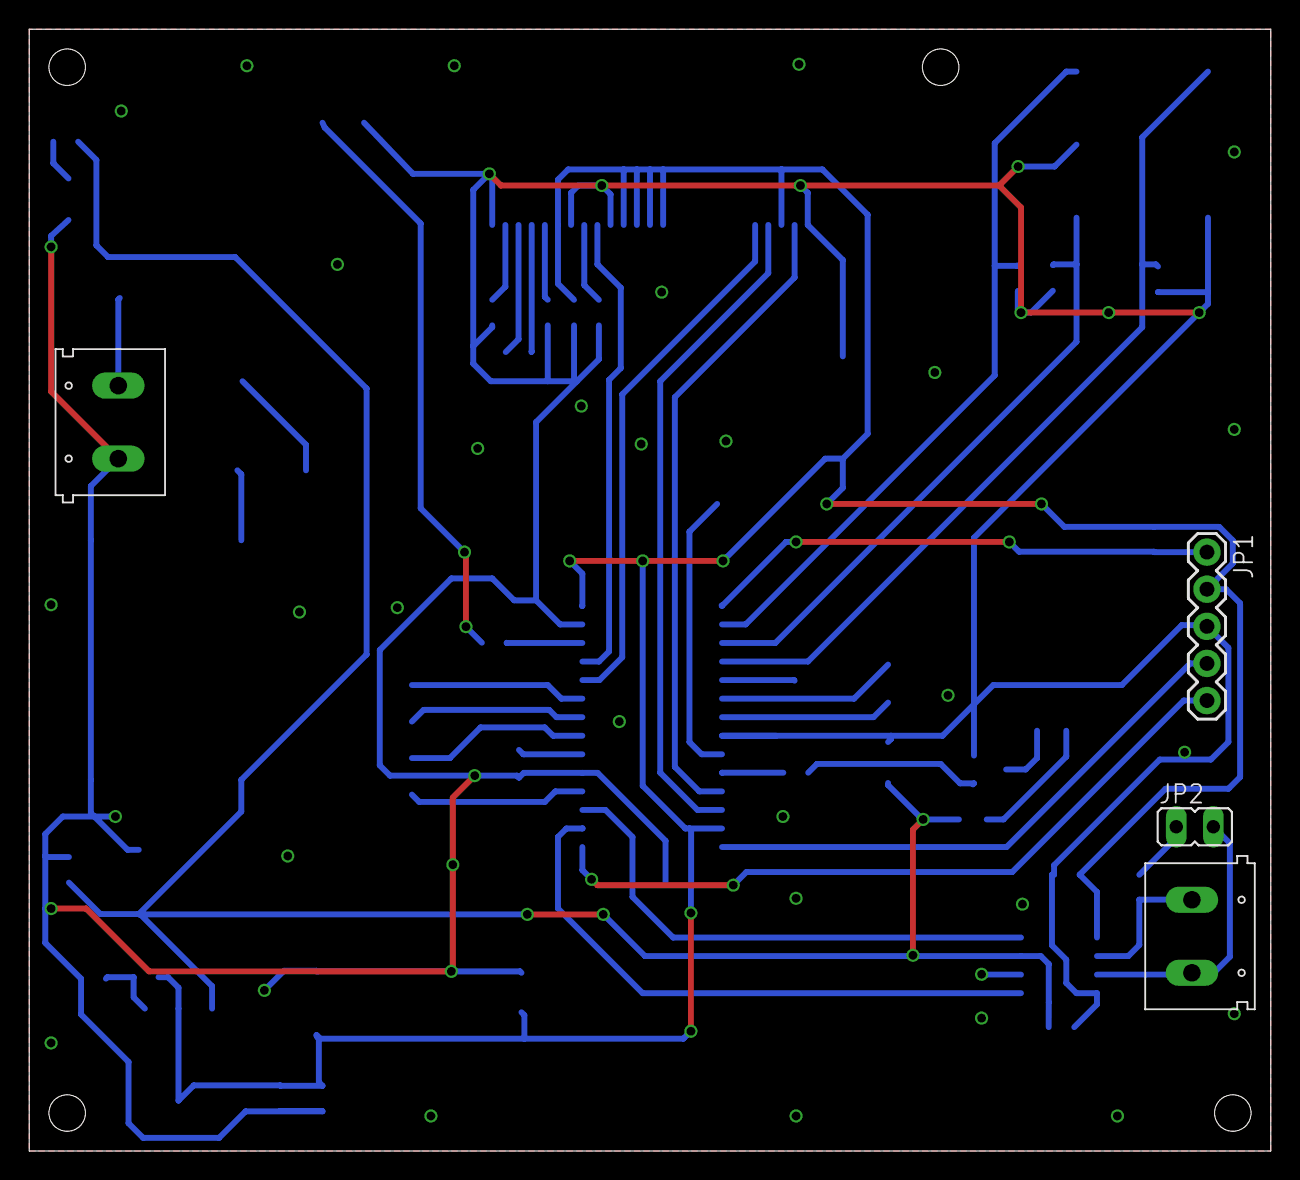
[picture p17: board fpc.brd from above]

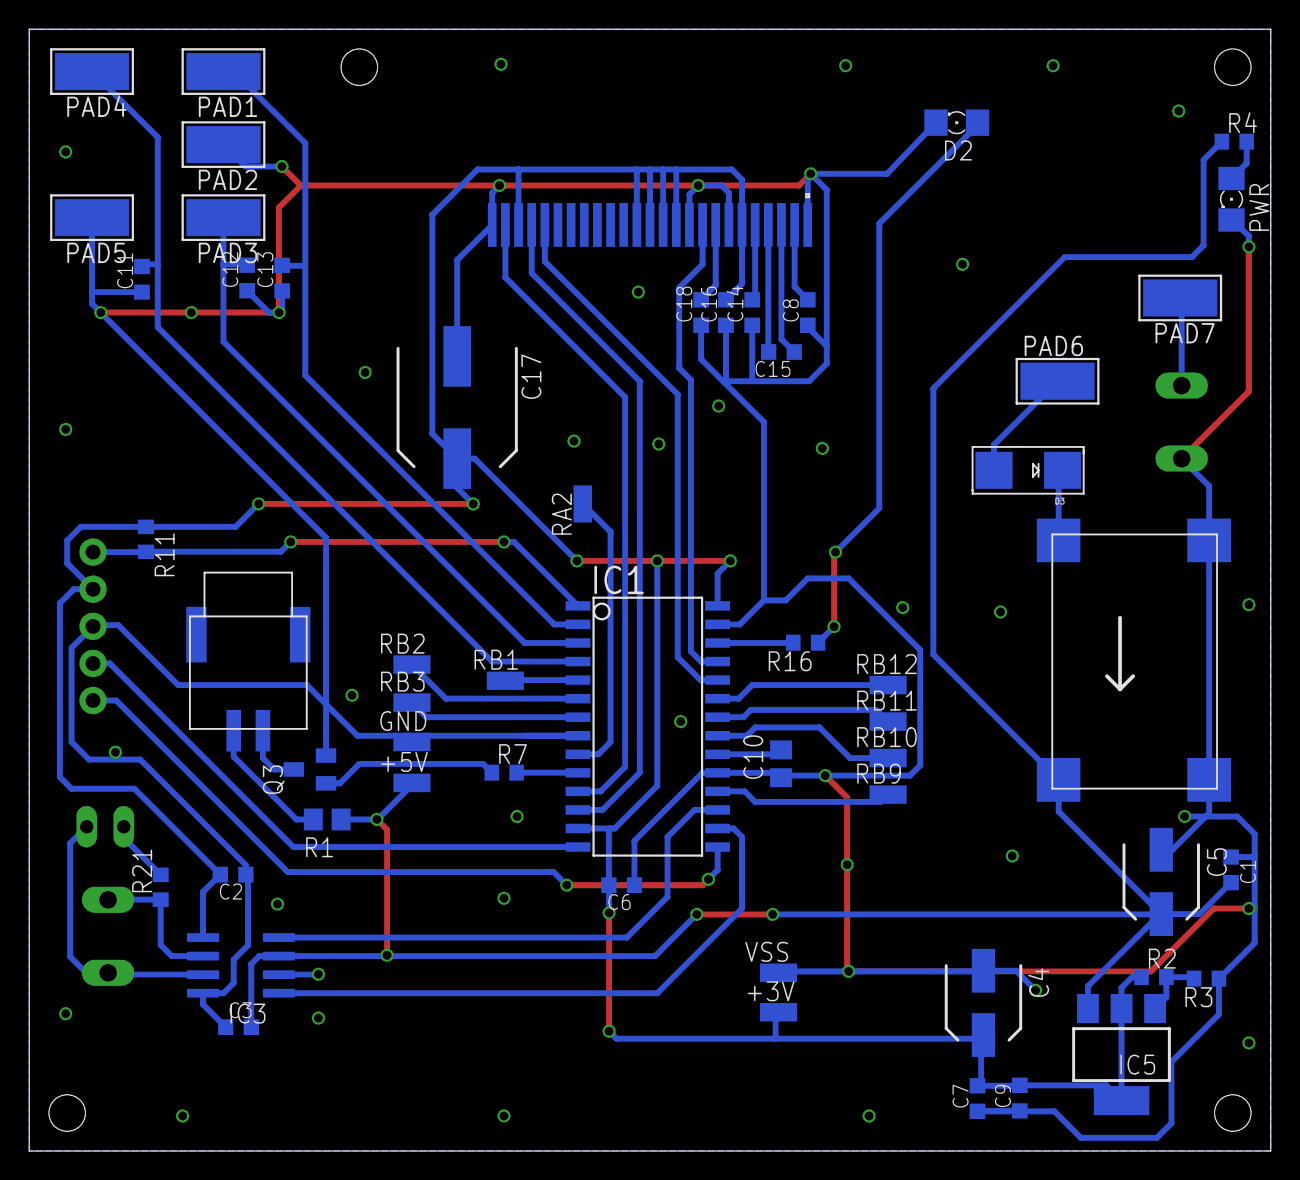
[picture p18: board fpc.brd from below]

Board: 2 copper layers, 85.0 x 76.8 mm, 59 parts (55 on the bottom side), 43 nets.

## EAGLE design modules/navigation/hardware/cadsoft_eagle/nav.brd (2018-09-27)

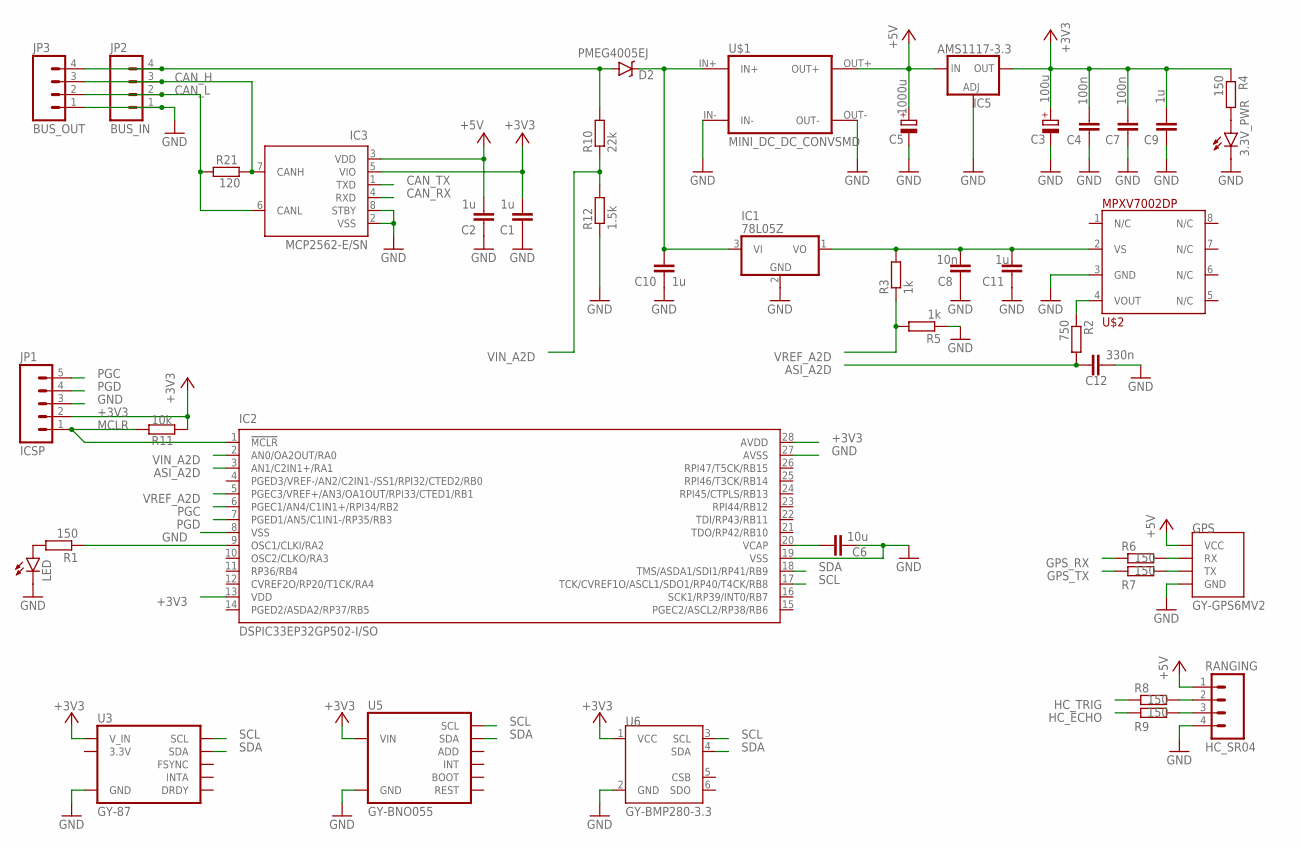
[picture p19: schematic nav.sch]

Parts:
3.3V_PWR: LED-FKIT-1206; FKIT-LED-1206
C1, C2, C11: 1u; C0603K
C3: 100u; E2,5-7
C4, C7: 100n; C0603K
C5: 1000u; E3,5-8
C6: 10u; C0805K
C8: 10n; C0603K
C9, C10: 1u; C0603
C12: 330n; C0603K
D2: PMEG4005EJ; SOD-323
GPS: GY-GPS6MV2
IC1: 78L05Z; TO92
IC2: DSPIC33EP32GP502-I/SO; SO28W
IC3: MCP2562-E/SN; SO-08
IC5: AMS1117-3.3; SOT223
JP1: ICSP; 1X05
JP2: BUS_IN; 1X04
JP3: BUS_OUT; 1X04
LED: LED-FKIT-1206; FKIT-LED-1206
R1, R4, R6, R7, R8, R9: 150; R0603
R2: 750; R0603
R3, R5: 1k; R0603
R10: 22k; R0603
R11: 10k; R0603
R12: 1.5k; R0603
R21: 120; R0603
RANGING: HC_SR04; 1X04
U3: GY-87
U5: GY-BNO055
U6: GY-BMP280-3.3
U$1: MINI_DC_DC_CONVSMD; DSN-MINI-360-SMD
U$2: MPXV7002DP

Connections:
3.3V: U3.3.3V
+3V3: C1.2, C3.+, C4.2, C7.2, C9.2, IC2.13 (VDD), IC2.28 (AVDD), IC3.5 (VIO), IC5.2 (OUT), IC5.@2 (OUT), JP1.2, R4.1, R11.1, U3.VCC_IN (V_IN), U5.VIN, U6.1 (VCC)
+5V: C2.2, C5.+, GPS.VCC, IC3.3 (VDD), IC5.3 (IN), RANGING.1, U$1.OUT+
ASI_A2D: C12.2, IC2.3 (AN1/C2IN1+/RA1), R2.2
CAN_H: IC3.7 (CANH), JP2.3, JP3.3, R21.2
CAN_L: IC3.6 (CANL), JP2.2, JP3.2, R21.1
CAN_RX: IC3.4 (RXD)
CAN_TX: IC3.1 (TXD)
GND: 3.3V_PWR.C, C1.1, C2.1, C3.-, C4.1, C5.-, C6.1, C7.1, C8.1, C9.1, C10.1, C11.1, C12.1, GPS.GND, IC1.2 (GND), IC2.8 (VSS), IC2.19 (VSS), IC2.27 (AVSS), IC3.2 (VSS), IC3.8 (STBY), IC5.1 (ADJ), JP1.3, JP2.1, JP3.1, LED.C, R5.1, R12.1, RANGING.4, U3.GND, U5.GND, U6.2 (GND), U$1.IN-, U$1.OUT-, U$2.3 (GND)
GPS_RX: R6.1
GPS_TX: R7.1
HC_ECHO: R9.1
HC_TRIG: R8.1
MCLR: IC2.1 (!MCLR!), JP1.1, R11.2
unnamed: C8.2, C11.2, IC1.1 (VO), R3.2, U$2.2 (VS)
unnamed: GPS.RX, R6.2
unnamed: 3.3V_PWR.A, R4.2
unnamed: LED.A, R1.2
unnamed: R2.1, U$2.4 (VOUT)
unnamed: GPS.TX, R7.2
unnamed: R8.2, RANGING.2
unnamed: R9.2, RANGING.3
unnamed: IC2.9 (OSC1/CLKI/RA2), R1.1
PGC: IC2.6 (PGEC1/AN4/C1IN1+/RPI34/RB2), JP1.5
PGD: IC2.7 (PGED1/AN5/C1IN1-/RP35/RB3), JP1.4
SCL: IC2.17 (TCK/CVREF1O/ASCL1/SDO1/RP40/T4CK/RB8), U3.SCL, U5.SCL, U6.3 (SCL)
SDA: IC2.18 (TMS/ASDA1/SDI1/RP41/RB9), U3.SDA, U5.SDA, U6.4 (SDA)
VCAP: C6.2, IC2.20 (VCAP)
VIN: D2.A, JP2.4, JP3.4, R10.2
VIN_A2D: IC2.2 (AN0/OA2OUT/RA0), R10.1, R12.2
VIN_D: C10.2, D2.C, IC1.3 (VI), U$1.IN+
VREF_A2D: IC2.5 (PGEC3/VREF+/AN3/OA1OUT/RPI33/CTED1/RB1), R3.1, R5.2

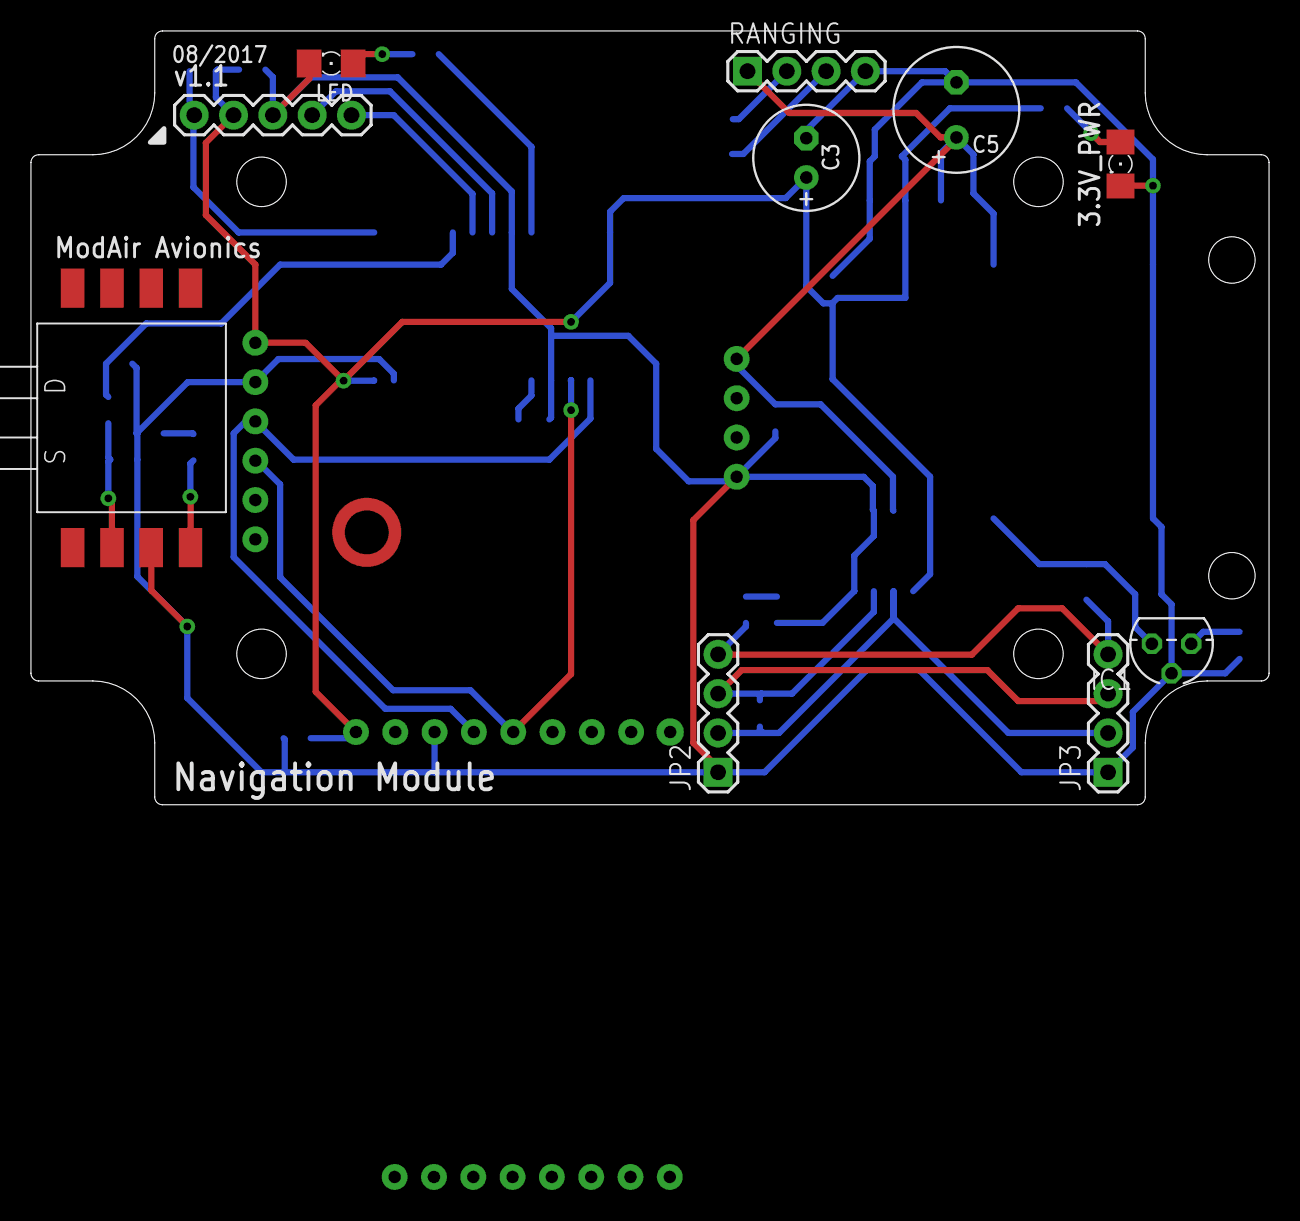
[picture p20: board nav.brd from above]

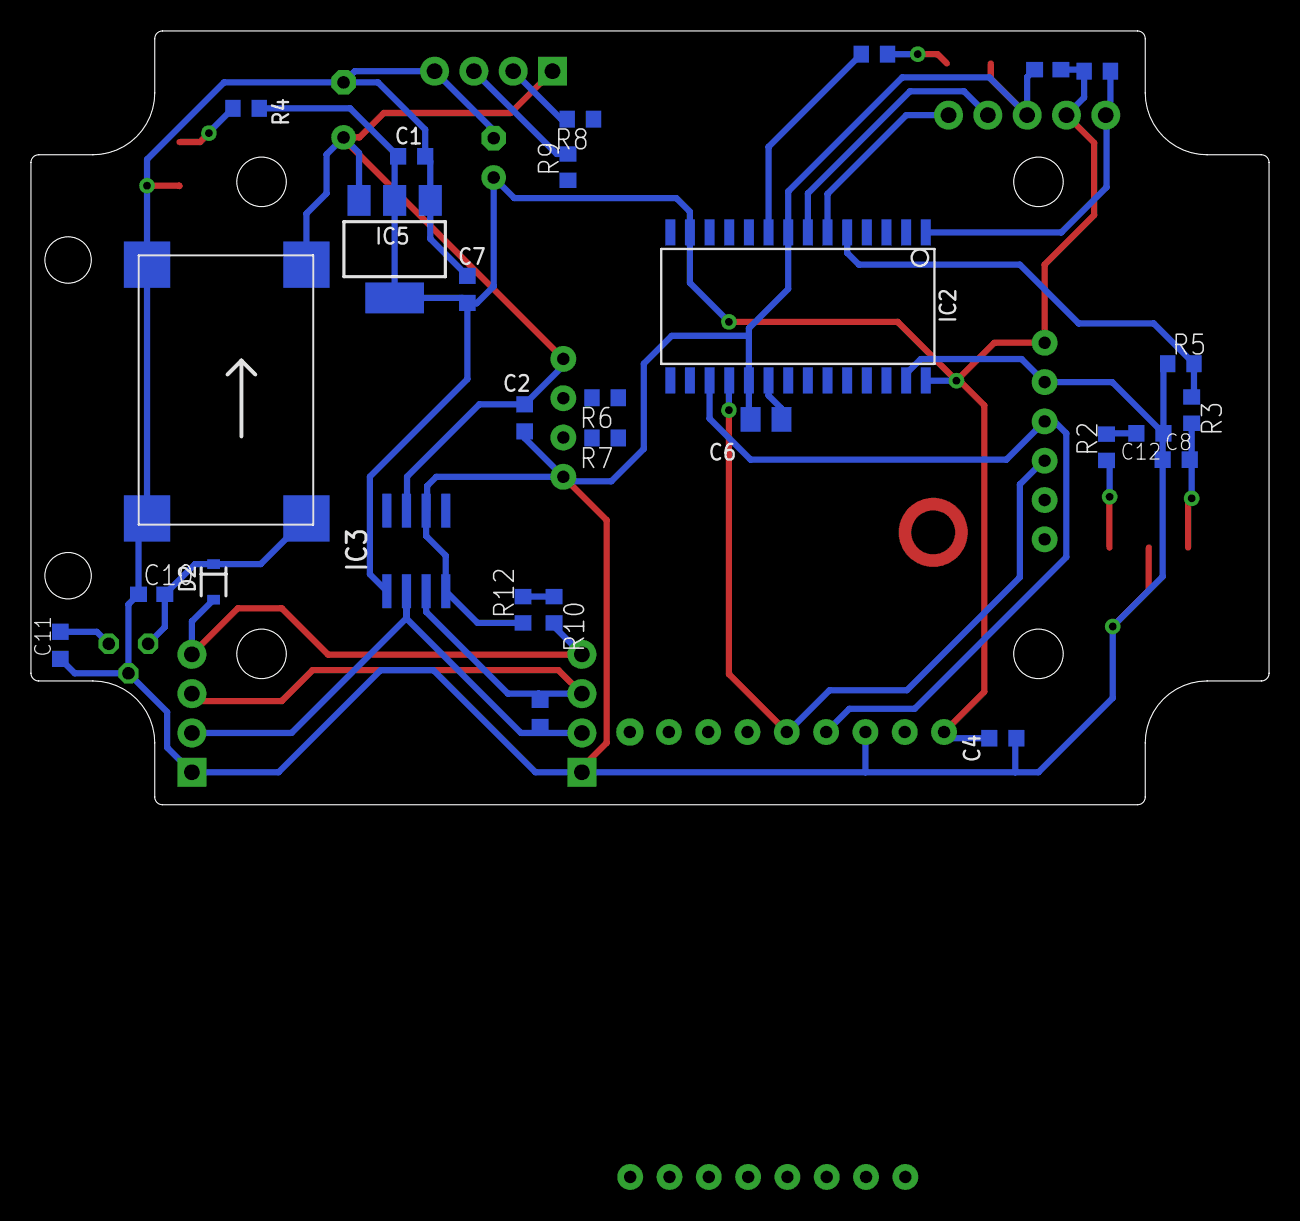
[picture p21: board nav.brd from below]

Board: 2 copper layers, 80.0 x 50.0 mm, 42 parts (29 on the bottom side), 25 nets.

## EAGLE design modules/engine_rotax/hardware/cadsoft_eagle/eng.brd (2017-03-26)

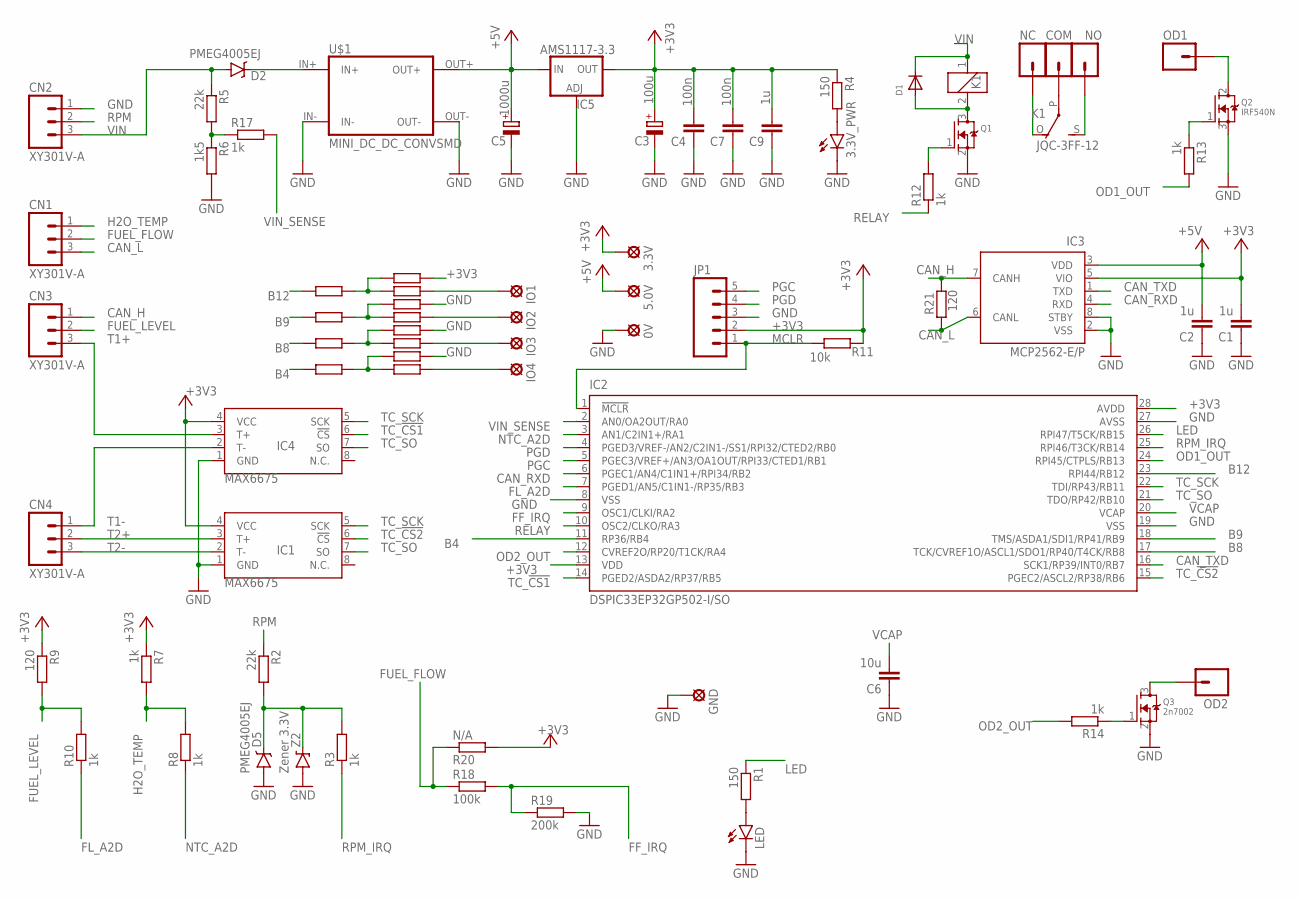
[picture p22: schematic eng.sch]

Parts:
0V, 3.3V, 5.0V: LSP10
3.3V_PWR: LED-FKIT-1206; FKIT-LED-1206
C1, C2: 1u; C0603K
C3: 100u; E2,5-7
C4, C7: 100n; C0603K
C5: 1000u; E3,5-8
C6: 10u; C3225
C9: 1u; C0603
CN1, CN2, CN3, CN4: XY301V-A
COM: M01PTH_LONGPAD; 1X01_LONGPAD
D1: DIODESMA; SMADIODE
D2, D5: PMEG4005EJ; SOD-323
GND: LSP10
IC1, IC4: MAX6675; SO08
IC2: DSPIC33EP32GP502-I/SO; SO28W
IC3: MCP2562-E/P; DIL8
IC5: AMS1117-3.3; SOT223
IO1, IO2, IO3, IO4: LSP10
JP1: M05PTH; 1X05
K1: JQC-3FF-12; G5LE
LED: LED-FKIT-1206; FKIT-LED-1206
NC: M01PTH_LONGPAD; 1X01_LONGPAD
NO: M01PTH_LONGPAD; 1X01_LONGPAD
OD1, OD2: M01PTH_LONGPAD; 1X01_LONGPAD
Q1: MOSFET-NREFLOW; SOT23
Q2: IRF540N; TO220V
Q3: 2n7002; SOT23
R1, R4: 150; R0603
R2, R5: 22k; R0603
R3, R7, R8, R10, R12, R13, R14, R17: 1k; R0603
R6: 1k5; R0603
R9, R21: 120; R0603
R11: 10k; R0603
R15, R16, R20, R23, R24, R25, R26, R29, R30, R31, R32, R35, R36: N/A; R0603
R18: 100k; R0603
R19: 200k; R0603
U$1: MINI_DC_DC_CONVSMD; DSN-MINI-360-SMD
Z2: Zener 3.3V; MINIMELF

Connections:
+3V3: 3.3V.MP, C1.2, C3.+, C4.2, C7.2, C9.2, IC1.4 (VCC), IC2.13 (VDD), IC2.28 (AVDD), IC3.5 (VIO), IC4.4 (VCC), IC5.2 (OUT), IC5.@2 (OUT), JP1.2, R4.1, R7.1, R9.1, R11.1, R20.2, R32.2
+5V: 5.0V.MP, C2.2, C5.+, IC3.3 (VDD), IC5.3 (IN), U$1.OUT+
B4: IC2.11 (RP36/RB4), R15.1
B8: IC2.17 (TCK/CVREF1O/ASCL1/SDO1/RP40/T4CK/RB8), R24.1
B9: IC2.18 (TMS/ASDA1/SDI1/RP41/RB9), R23.1
B12: IC2.23 (RPI44/RB12), R16.1
CAN_H: CN3.1, IC3.7 (CANH), R21.2
CAN_L: CN1.3, IC3.6 (CANL), R21.1
CAN_RXD: IC2.6 (PGEC1/AN4/C1IN1+/RPI34/RB2), IC3.4 (RXD)
CAN_TXD: IC2.16 (SCK1/RP39/INT0/RB7), IC3.1 (TXD)
FF_IRQ: IC2.9 (OSC1/CLKI/RA2), R18.2, R19.1
FL_A2D: IC2.7 (PGED1/AN5/C1IN1-/RP35/RB3), R10.1
FUEL_FLOW: CN1.2, R18.1, R20.1
FUEL_LEVEL: CN3.2, R9.2, R10.2
GND: 0V.MP, 3.3V_PWR.C, C1.1, C2.1, C3.-, C4.1, C5.-, C6.1, C7.1, C9.1, CN2.1, D5.A, GND.MP, IC1.1 (GND), IC2.8 (VSS), IC2.19 (VSS), IC2.27 (AVSS), IC3.2 (VSS), IC3.8 (STBY), IC4.1 (GND), IC5.1 (ADJ), JP1.3, LED.C, Q1.2 (S), Q2.3 (S), Q3.2 (S), R6.2, R19.2, R31.2, R35.2, R36.2, U$1.IN-, U$1.OUT-, Z2.A
H2O_TEMP: CN1.1, R7.2, R8.2
LED: IC2.26 (RPI47/T5CK/RB15), R1.1
MCLR: IC2.1 (!MCLR!), JP1.1, R11.2
unnamed: D1.A, K1.2, Q1.3 (D)
unnamed: Q1.1 (G), R12.2
unnamed: 3.3V_PWR.A, R4.2
unnamed: LED.A, R1.2
unnamed: Q2.1 (G), R13.1
unnamed: COM.1, K1.P
unnamed: K1.O, NC.1
unnamed: K1.S, NO.1
unnamed: OD1.1, Q2.2 (D)
unnamed: OD2.1, Q3.3 (D)
unnamed: Q3.1 (G), R14.1
unnamed: R15.2, R25.1, R31.1
unnamed: R16.2, R26.1, R32.1
unnamed: R5.2, R6.1, R17.1
unnamed: R23.2, R29.1, R35.1
unnamed: R24.2, R30.1, R36.1
unnamed: IO3.MP, R30.2
unnamed: IO2.MP, R29.2
unnamed: IO1.MP, R26.2
unnamed: IO4.MP, R25.2
NTC_A2D: IC2.3 (AN1/C2IN1+/RA1), R8.1
OD1_OUT: IC2.24 (RPI45/CTPLS/RB13), R13.2
OD2_OUT: IC2.12 (CVREF2O/RP20/T1CK/RA4), R14.2
PGC: IC2.5 (PGEC3/VREF+/AN3/OA1OUT/RPI33/CTED1/RB1), JP1.5
PGD: IC2.4 (PGED3/VREF-/AN2/C2IN1-/SS1/RPI32/CTED2/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), JP1.4
RELAY: IC2.10 (OSC2/CLKO/RA3), R12.1
RPM: CN2.2, R2.1
RPM_IRQ: IC2.25 (RPI46/T3CK/RB14), R3.1
RPM_Z: D5.C, R2.2, R3.2, Z2.C
T1+: CN3.3, IC4.3 (T+)
T1-: CN4.1, IC4.2 (T-)
T2+: CN4.2, IC1.3 (T+)
T2-: CN4.3, IC1.2 (T-)
TC_!CS1: IC2.14 (PGED2/ASDA2/RP37/RB5), IC4.6 (!CS)
TC_!CS2: IC1.6 (!CS), IC2.15 (PGEC2/ASCL2/RP38/RB6)
TC_SCK: IC1.5 (SCK), IC2.22 (TDI/RP43/RB11), IC4.5 (SCK)
TC_SO: IC1.7 (SO), IC2.21 (TDO/RP42/RB10), IC4.7 (SO)
VCAP: C6.2, IC2.20 (VCAP)
VIN: CN2.3, D1.C, D2.A, K1.1, R5.1
VIN_D: D2.C, U$1.IN+
VIN_SENSE: IC2.2 (AN0/OA2OUT/RA0), R17.2

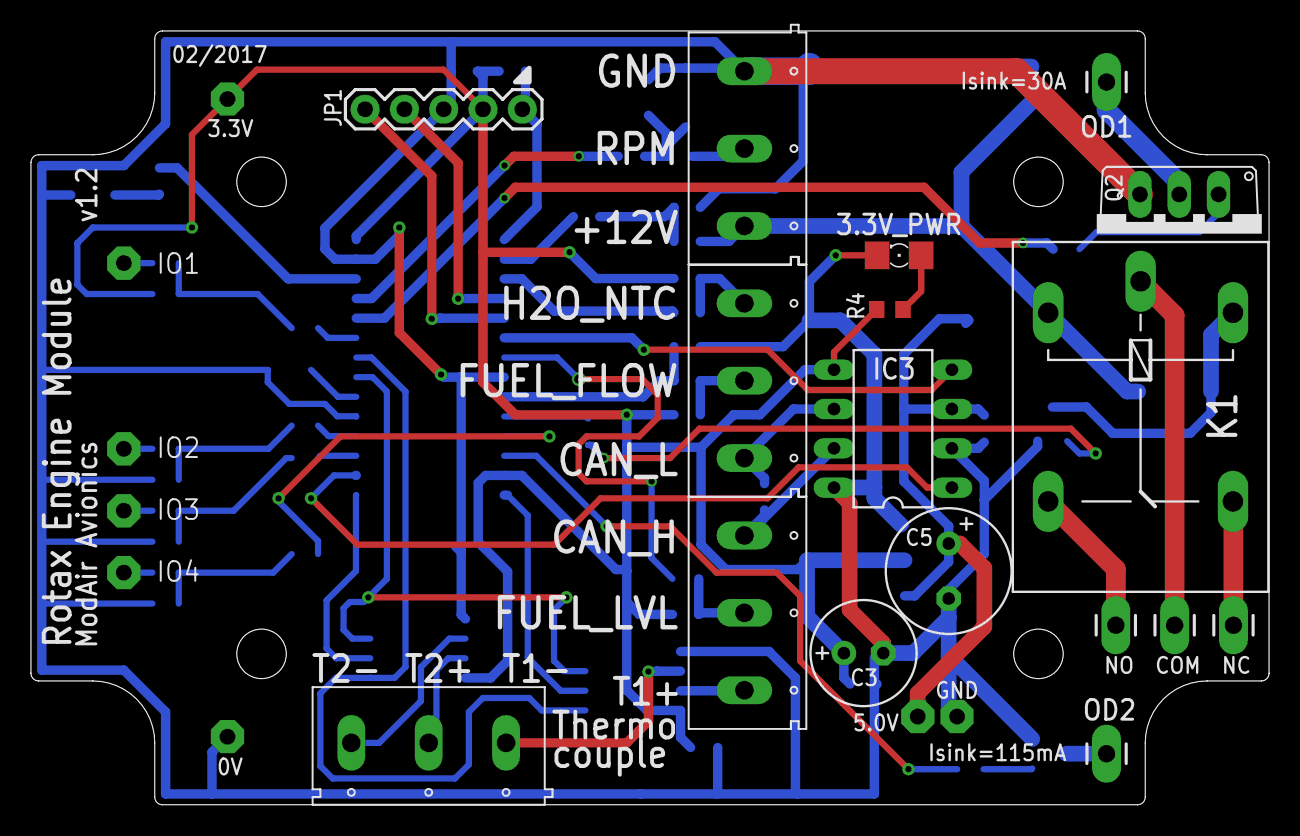
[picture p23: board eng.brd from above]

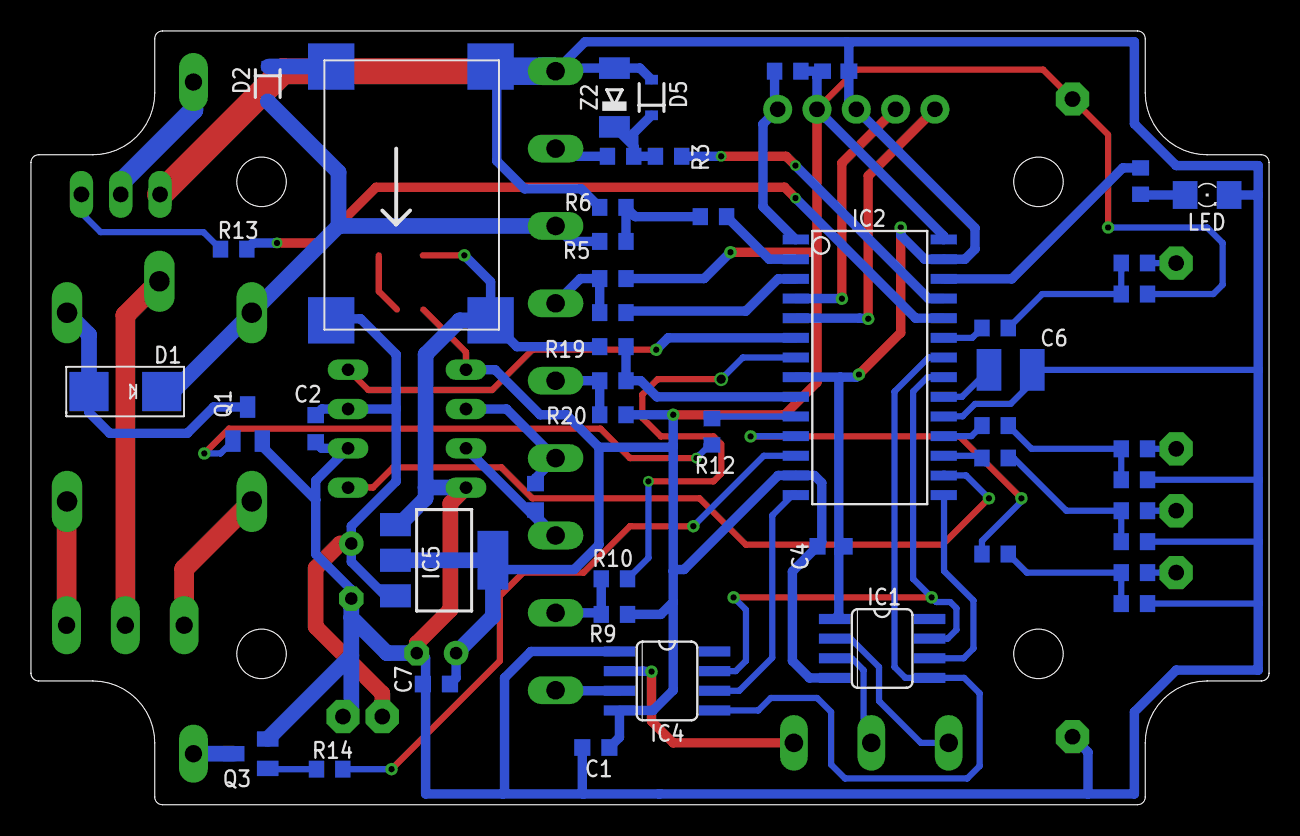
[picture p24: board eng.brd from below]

Board: 2 copper layers, 80.0 x 50.0 mm, 73 parts (48 on the bottom side), 59 nets.

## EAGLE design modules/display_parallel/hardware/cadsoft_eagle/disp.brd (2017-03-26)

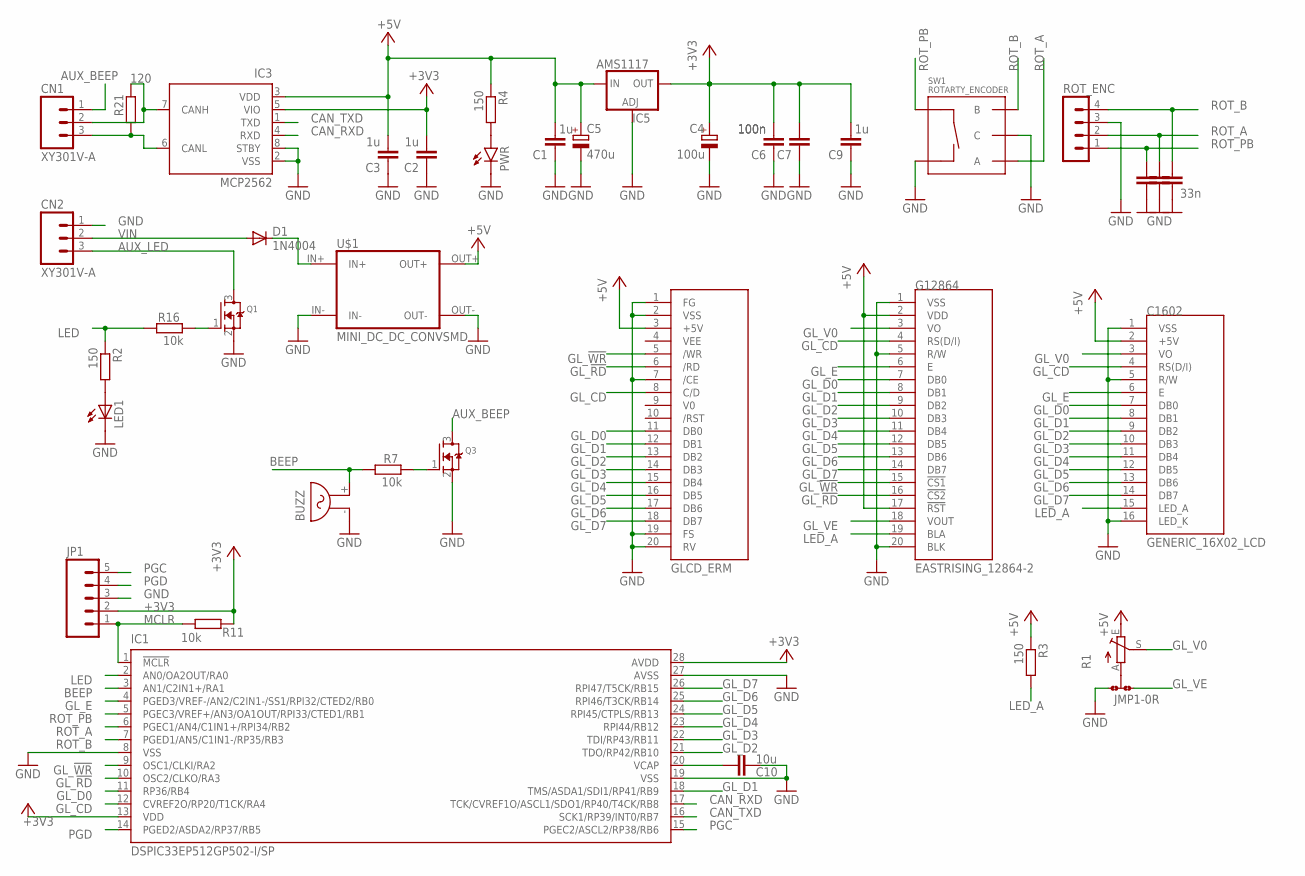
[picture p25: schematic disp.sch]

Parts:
BUZZ: F/QMX
C1, C2, C3, C9: 1u; C0603K
C4: 100u; E2,5-7
C5: 470u; E3,5-8
C6, C7: 100n; C0603K
C10: 10u; C025-030X050
C11, C12, C13: 33n; C0603K
C1602: GENERIC_16X02_LCD; 1X16
CN1, CN2: XY301V-A
D1: 1N4004; DO41-10
G12864: EASTRISING_12864-2; 1X20
GLCD_ERM: WITSCHI_ERM25664AAG-1; 1X20
IC1: DSPIC33EP512GP502-I/SP; DIL28-3
IC3: MCP2562; DIL8
IC5: AMS1117; SOT223
JMP1: 0R-JUMPB; B0R-JMP
JP1: M05PTH; 1X05
LED1: LED5MM
PWR: LED-FKIT-1206; FKIT-LED-1206
Q1, Q3: MOSFET-NREFLOW; SOT23
R1: TRIM_EU-B64Y; B64Y
R2, R3, R4: 150; R0603
R7, R11, R16: 10k; R0603
R21: 120; R0603
ROT_ENC: MA04-1
SW1: ROTARTY_ENCODER; ROTARY_ENC_PLAIN
U$1: MINI_DC_DC_CONVSMD; DSN-MINI-360-SMD

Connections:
+3V3: C2.2, C4.+, C6.2, C7.2, C9.2, IC1.13 (VDD), IC1.28 (AVDD), IC3.5 (VIO), IC5.2 (OUT), IC5.@2 (OUT), JP1.2, R11.1
+5V: C1.2, C3.2, C5.+, C1602.2 (+5V), G12864.2 (VDD), G12864.17 (!RST), GLCD_ERM.3 (+5V), IC3.3 (VDD), IC5.3 (IN), R1.E, R3.1, R4.1, U$1.OUT+
AUX_BEEP: CN1.1, Q3.3 (D)
AUX_LED: CN2.3, Q1.3 (D)
BEEP: BUZZ.+ (2), IC1.3 (AN1/C2IN1+/RA1), R7.2
CAN_H: CN1.2, IC3.7 (CANH), R21.2
CAN_L: CN1.3, IC3.6 (CANL), R21.1
CAN_RXD: IC1.17 (TCK/CVREF1O/ASCL1/SDO1/RP40/T4CK/RB8), IC3.4 (RXD)
CAN_TXD: IC1.16 (SCK1/RP39/INT0/RB7), IC3.1 (TXD)
GL_!RD: G12864.16 (!CS2), GLCD_ERM.6 (/RD), IC1.10 (OSC2/CLKO/RA3)
GL_!WR: G12864.15 (!CS1), GLCD_ERM.5 (/WR), IC1.9 (OSC1/CLKI/RA2)
GL_CD: C1602.4 (RS(D/I)), G12864.4 (RS(D/I)), GLCD_ERM.8 (C/D), IC1.12 (CVREF2O/RP20/T1CK/RA4)
GL_D0: C1602.7 (DB0), G12864.7 (DB0), GLCD_ERM.11 (DB0), IC1.11 (RP36/RB4)
GL_D1: C1602.8 (DB1), G12864.8 (DB1), GLCD_ERM.12 (DB1), IC1.18 (TMS/ASDA1/SDI1/RP41/RB9)
GL_D2: C1602.9 (DB2), G12864.9 (DB2), GLCD_ERM.13 (DB2), IC1.21 (TDO/RP42/RB10)
GL_D3: C1602.10 (DB3), G12864.10 (DB3), GLCD_ERM.14 (DB3), IC1.22 (TDI/RP43/RB11)
GL_D4: C1602.11 (DB4), G12864.11 (DB4), GLCD_ERM.15 (DB4), IC1.23 (RPI44/RB12)
GL_D5: C1602.12 (DB5), G12864.12 (DB5), GLCD_ERM.16 (DB5), IC1.24 (RPI45/CTPLS/RB13)
GL_D6: C1602.13 (DB6), G12864.13 (DB6), GLCD_ERM.17 (DB6), IC1.25 (RPI46/T3CK/RB14)
GL_D7: C1602.14 (DB7), G12864.14 (DB7), GLCD_ERM.18 (DB7), IC1.26 (RPI47/T5CK/RB15)
GL_E: C1602.6 (E), G12864.6 (E), IC1.4 (PGED3/VREF-/AN2/C2IN1-/SS1/RPI32/CTED2/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)
GL_V0: C1602.3 (VO), G12864.3 (VO), R1.S
GL_VE: G12864.18 (VOUT), JMP1.3
GND: BUZZ.- (1), C1.1, C2.1, C3.1, C4.-, C5.-, C6.1, C7.1, C9.1, C10.1, C11.1, C12.1, C13.1, C1602.1 (VSS), C1602.5 (R/W), C1602.16 (LED_K), CN2.1, G12864.1 (VSS), G12864.5 (R/W), G12864.20 (BLK), GLCD_ERM.1 (FG), GLCD_ERM.2 (VSS), GLCD_ERM.7 (/CE), GLCD_ERM.19 (FS), GLCD_ERM.20 (RV), IC1.8 (VSS), IC1.19 (VSS), IC1.27 (AVSS), IC3.2 (VSS), IC3.8 (STBY), IC5.1 (ADJ), JMP1.1, JP1.3, LED1.K (C), PWR.C, Q1.2 (S), Q3.2 (S), ROT_ENC.3, SW1.C, SW1.SW-, U$1.IN-, U$1.OUT-
LED: IC1.2 (AN0/OA2OUT/RA0), R2.1, R16.2
LED_A: C1602.15 (LED_A), G12864.19 (BLA), R3.2
MCLR: IC1.1 (!MCLR!), JP1.1, R11.2
unnamed: Q3.1 (G), R7.1
unnamed: LED1.A, R2.2
unnamed: PWR.A, R4.2
unnamed: JMP1.2, R1.A
unnamed: Q1.1 (G), R16.1
PGC: IC1.15 (PGEC2/ASCL2/RP38/RB6), JP1.5
PGD: IC1.14 (PGED2/ASDA2/RP37/RB5), JP1.4
ROT_A: C12.2, IC1.6 (PGEC1/AN4/C1IN1+/RPI34/RB2), ROT_ENC.2, SW1.A
ROT_B: C13.2, IC1.7 (PGED1/AN5/C1IN1-/RP35/RB3), ROT_ENC.4, SW1.B
ROT_PB: C11.2, IC1.5 (PGEC3/VREF+/AN3/OA1OUT/RPI33/CTED1/RB1), ROT_ENC.1, SW1.SW+
V0: GLCD_ERM.9 (V0)
VCAP: C10.2, IC1.20 (VCAP)
VEE: GLCD_ERM.4 (VEE)
VIN: CN2.2, D1.A
VIN_D: D1.C, U$1.IN+

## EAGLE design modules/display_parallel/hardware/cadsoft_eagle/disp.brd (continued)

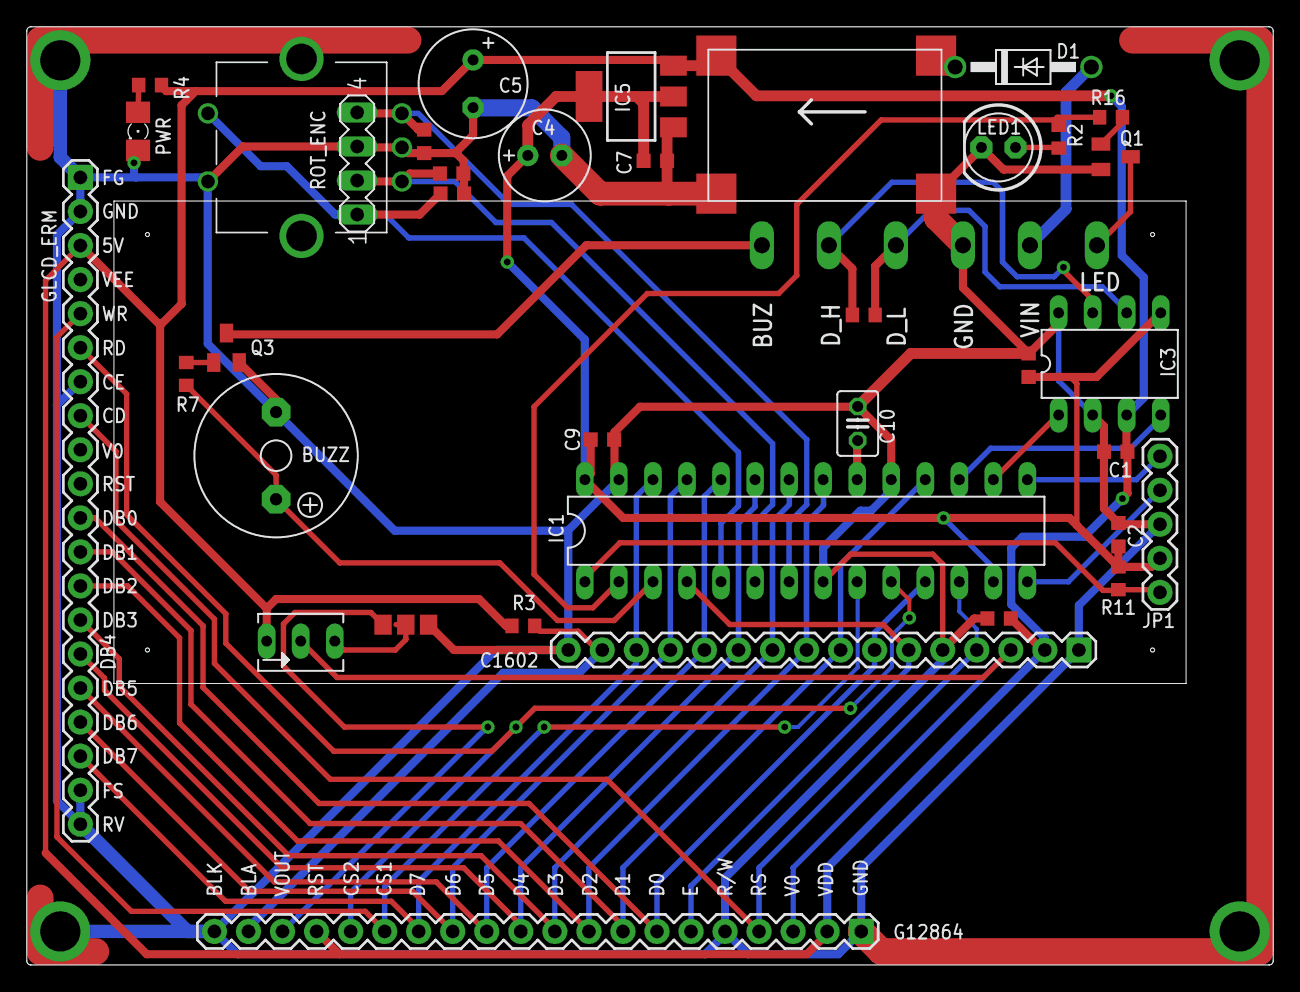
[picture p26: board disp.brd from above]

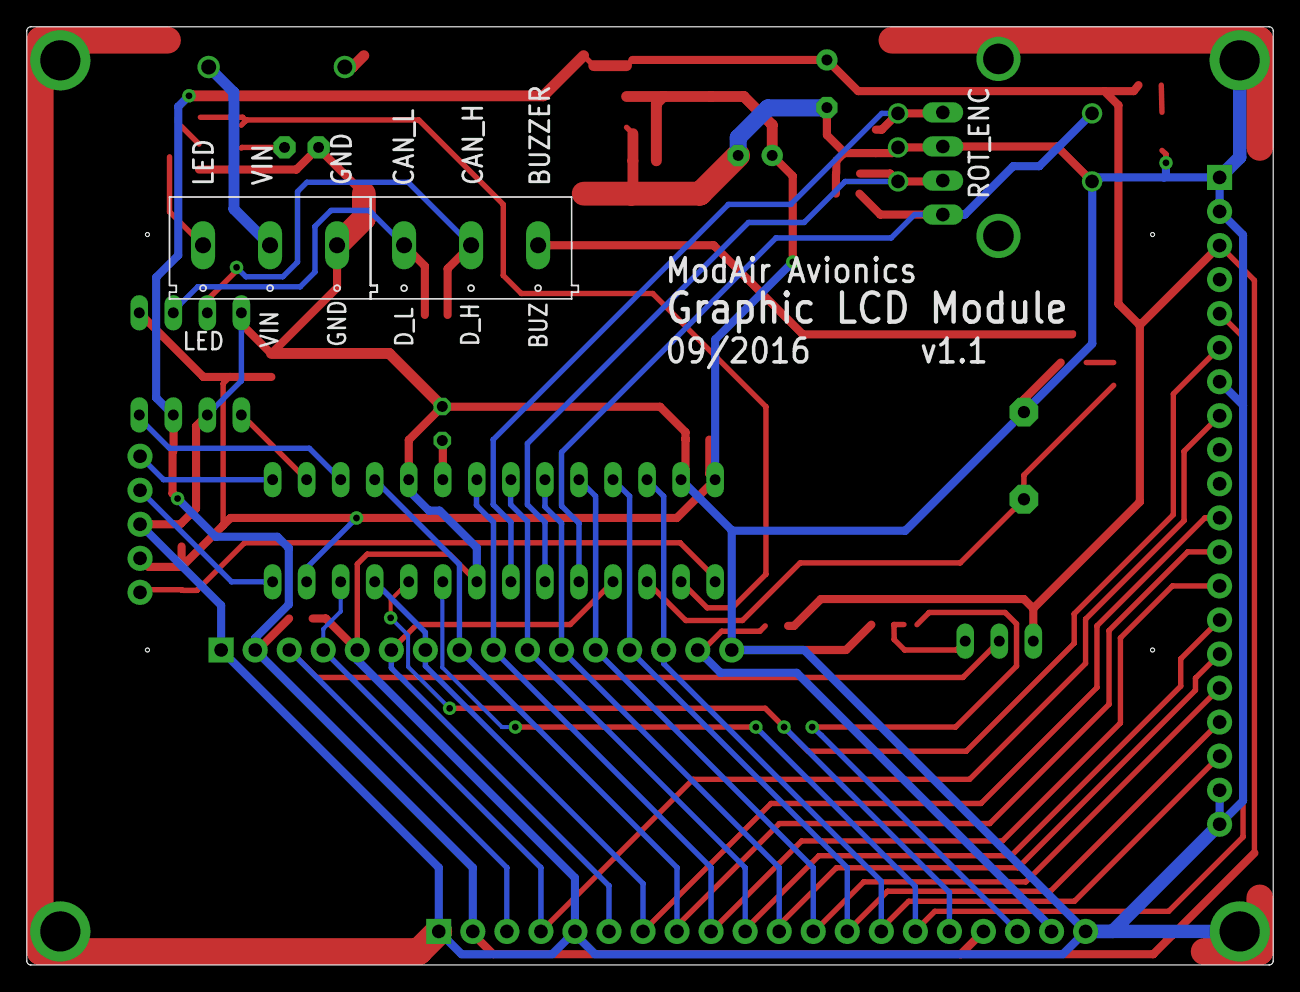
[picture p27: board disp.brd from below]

Board: 2 copper layers, 93.0 x 70.0 mm, 39 parts (2 on the bottom side), 40 nets.

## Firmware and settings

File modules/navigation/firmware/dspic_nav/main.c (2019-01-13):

#include "xc.h"
#include <stdio.h>
#include <stdlib.h>
#include <string.h>
#include "common.h"
#include "config_bits.h"
#include "iopins.h"
#include "analog.h"
#include "fuellevel.h"
#include "busvoltage.h"
#include "watertemp.h"
#include "ecan_mod.h"
#include "modair_bus.h"
#include "params.h"
#include "module_console.h"
#include "i2c.h"
#include "bmp180_driv.h"
#include "mpu6050_driv.h"
#include "hmc5883_driv.h"
#include "fuelflow.h"
#include "rpm.h"
#include "thermocouple.h"

//==============================================================================
//--------------------FUNCTION PROTOTYPES---------------------------------------
//==============================================================================
void module_ecanrx(u8 idx, u16 pid, u16 *data, u8 msg_type, u8 flags, u8 len);

//==============================================================================
//--------------------GLOBAL VARIABLES------------------------------------------
//==============================================================================
//s_param_settings PARAM_LIST[PARAM_CNT];
u16 rate_cnt[PARAM_CNT];

// use function pointers to navigate through the module menu;
void* (*current_menu_fnc)(u8,u8) = 0;

// temporary settings record for flash memory read-modify-erase-write
s_settings tmp_settings;

//==============================================================================
//--------------------GLOBAL CONSTANTS------------------------------------------
//==============================================================================
// create a non-volatile program memory region 'nvmdata' at a page boundary,
// and store the user settings record there. Map the program memory region into
// data-memory using the PSV mechanism. The entire flash memory page needs to be
// erased before new settings can be written.
__attribute__((aligned(_FLASH_PAGE*2),space(psv),section(".nvmdata"))) const volatile s_settings settings = {
    .param = {
        {.pid=0xFF03, .name="Rotax582", .rate=0}, // MODULE
        {.pid=0x0091, .name="Air Pres", .rate=50}, // 1 Hz
        {.pid=0x0092, .name="QNH     ", .rate=0},  // 0 Hz
        {.pid=0x0093, .name="Alt FL  ", .rate=5},  // 10 Hz
        {.pid=0x0094, .name="Alt QNH ", .rate=5},  // 10 Hz
        {.pid=0x0095, .name="Air Temp", .rate=50}, // 1 Hz
        {.pid=0x0019, .name="RELAY   ", .rate=50},
        {.pid=0x001A, .name="OD1 OUT ", .rate=50},
        {.pid=0x001B, .name="OD2 OUT ", .rate=50},
        {.pid=0x0017, .name="FUEL LVL", .rate=10}, // 5 Hz
        {.pid=0x0010, .name="BUS VOLT", .rate=50}, // 1 Hz
        {.pid=0x0018, .name="H2O TEMP", .rate=10}, // 5 Hz
        {.pid=0x0011, .name="EGT 1   ", .rate=12}, // ~4 Hz
        {.pid=0x0012, .name="EGT 2   ", .rate=12}, // ~4 Hz
        {.pid=0x0013, .name="RPM     ", .rate=25}, // 2 Hz
        {.pid=0x0014, .name="ENG HRS ", .rate=50}, // 1 Hz
        {.pid=0x0015, .name="ENG ON  ", .rate=50}, // 1 Hz
        {.pid=0x0016, .name="MAINTAIN", .rate=50}, // 1 Hz
        {.pid=0x001C, .name="FF INST ", .rate=10}, // 5 Hz
        {.pid=0x001D, .name="FF AVE  ", .rate=10}, // 5 Hz
        {.pid=0x001E, .name="FUEL END", .rate=25}, // 2 Hz
        {.pid=0x001F, .name="FUEL RNG", .rate=25}, // 2 Hz
        {.pid=0x0020, .name="FUEL USE", .rate=25}, // 2 Hz
        {.pid=0x00A0, .name="HMC5883 ", .rate=50}, // 1 Hz
        {.pid=0x00A1, .name="MPU6050 ", .rate=50}  // 1 Hz
    },
    .fuellevel_rom = { // converts ADC value to fuel level in 0.01 liter
        .FLx = {0,360,700,975,1203,1400,1590,1750,1900,2030,2150,2250,2350,2435,2510,2600},
        .FLy = {0,300,647,982,1310,1637,2000,2353,2730,3099,3487,3845,4249,4626,4995,5488}
    },
    .watertemp_rom = { // converts ADC value to water temperature in 0.1 degrees
        .WTx = {0,41,72,126,239,360,638,1154,3320,3740,3892,3986,4095,4095,4095,4095},
        .WTy = {2000,1800,1500,1240,1000,840,650,440,-40,-190,-300,0,0,0,0,0}
    },
    .rmp_mul = 20, // CNTs per 0.5s => 2.0 (cnts/sec) * 60.0 (cnts/min) / 6.0 (rotax582 setting?)
    .engine_hobbs = 1016.05,
    .maintainance_date = {22,04,19}, // dd,mm,20yy
    .maintainance_date_pid = 0 // linked PID that provides today's date
};

// register new parameter function handlers here; same order as settings.param[]
const s_param_fptr PARAM_CONST[PARAM_CNT] = {
    {.canrx_fnc_ptr=&module_ecanrx, .sendval_fnc_ptr=0,                    .menu_fnc_ptr=&menu_fnc_homescreen          }, // MODULE
    {.canrx_fnc_ptr=0,              .sendval_fnc_ptr=&bmp180_sendpres,     .menu_fnc_ptr=&bmp180_homescreen            }, // Air Pressure in Pa
    {.canrx_fnc_ptr=0,              .sendval_fnc_ptr=&bmp180_sendqnh,      .menu_fnc_ptr=&bmp180_editqnh               }, // QNH
    {.canrx_fnc_ptr=0,              .sendval_fnc_ptr=&bmp180_sendaltfl,    .menu_fnc_ptr=&bmp180_homescreen            }, // Altitude: Flight Level (i.e. QNH=101325 Pa)
    {.canrx_fnc_ptr=0,              .sendval_fnc_ptr=&bmp180_sendaltqnh,   .menu_fnc_ptr=&bmp180_homescreen            }, // Pressure Altitude: Based on user QNH
    {.canrx_fnc_ptr=0,              .sendval_fnc_ptr=&bmp180_sendtemp,     .menu_fnc_ptr=&bmp180_homescreen            }, // Outside Air Temperature in degrees C
    {.canrx_fnc_ptr=&iopins_ecanrx, .sendval_fnc_ptr=&iopins_sendrelay,    .menu_fnc_ptr=&iopins_relay_menu            }, // Relay Output
    {.canrx_fnc_ptr=&iopins_ecanrx, .sendval_fnc_ptr=&iopins_sendod1,      .menu_fnc_ptr=&iopins_od1_menu              }, // Open Drain 1 Output
    {.canrx_fnc_ptr=&iopins_ecanrx, .sendval_fnc_ptr=&iopins_sendod2,      .menu_fnc_ptr=&iopins_od2_menu              }, // Open Drain 2 Output
    {.canrx_fnc_ptr=0,              .sendval_fnc_ptr=&fuellevel_cntdwn,    .menu_fnc_ptr=&fuellevel_menu               }, // Fuel Level
    {.canrx_fnc_ptr=0,              .sendval_fnc_ptr=&busvoltage_cntdwn,   .menu_fnc_ptr=&busvoltage_menu              }, // Bus Voltage
    {.canrx_fnc_ptr=0,              .sendval_fnc_ptr=&watertemp_cntdwn,    .menu_fnc_ptr=&watertemp_menu               }, // Water Temperature
    {.canrx_fnc_ptr=0,              .sendval_fnc_ptr=&thermocouple_cntdwn, .menu_fnc_ptr=&thermocouple_fnc_homescreen  }, // Thermocouple 1
    {.canrx_fnc_ptr=0,              .sendval_fnc_ptr=&thermocouple_cntdwn, .menu_fnc_ptr=&thermocouple_fnc_homescreen  }, // Thermocouple 2
    {.canrx_fnc_ptr=0,              .sendval_fnc_ptr=&rpm_sendval,         .menu_fnc_ptr=0                             }, // RPM
    {.canrx_fnc_ptr=0,              .sendval_fnc_ptr=&enginehours_sendval, .menu_fnc_ptr=&enginehours_menu             }, // Engine Hours / Hobbs Meter
    {.canrx_fnc_ptr=0,              .sendval_fnc_ptr=&engineon_sendval,    .menu_fnc_ptr=&enginehours_menu             }, // Engine On Time since started
    {.canrx_fnc_ptr=0,              .sendval_fnc_ptr=0,                    .menu_fnc_ptr=0                             }, // Maintenance Timer
    {.canrx_fnc_ptr=0,              .sendval_fnc_ptr=0,                    .menu_fnc_ptr=0                             }, // Fuel Flow Instantaneous
    {.canrx_fnc_ptr=0,              .sendval_fnc_ptr=0,                    .menu_fnc_ptr=0                             }, // Fuel Flow Average since started
    {.canrx_fnc_ptr=0,              .sendval_fnc_ptr=0,                    .menu_fnc_ptr=0                             }, // Time to Empty Tank (fuel endurance)
    {.canrx_fnc_ptr=0,              .sendval_fnc_ptr=0,                    .menu_fnc_ptr=0                             }, // Range to Empty Tank (fuel range)
    {.canrx_fnc_ptr=0,              .sendval_fnc_ptr=0,                    .menu_fnc_ptr=0                             }, // Fuel Burned
    {.canrx_fnc_ptr=0,              .sendval_fnc_ptr=0,                    .menu_fnc_ptr=&hmc5883_homescreen           },
    {.canrx_fnc_ptr=0,              .sendval_fnc_ptr=0,                    .menu_fnc_ptr=&mpu6050_homescreen           }
};

//==============================================================================
//--------------------INTERRUPTS------------------------------------------------
//==============================================================================
void __attribute__((interrupt, auto_psv)) _T1Interrupt(void)
{
    u8 i;
    for (i=1;i<PARAM_CNT;i++)
        if (rate_cnt[i])
            rate_cnt[i]--;
    rpm_tmr_irq();
    _T1IF = 0;  // clear the interrupt
}

void __attribute__((interrupt, auto_psv)) _T2Interrupt(void)
{
    bmp180_tmr_irq();
    _T2IF = 0;  // clear the interrupt
}

void __attribute__((interrupt, auto_psv)) _CNInterrupt(void)
{
    fuelflow_cn_irq();
    rpm_cn_irq();
    _CNIF = 0;  // clear the interrupt
}

void __attribute__((interrupt, auto_psv)) _AD1Interrupt(void)
{
    analog_irq();
    _AD1IF = 0;  // clear the interrupt
}

//==============================================================================
//--------------------INIT FUNCTIONS--------------------------------------------
//==============================================================================
void tmr1_init(u16 freq_hz)
{
    T1CON = 0b1000000000110000; // TMR1 on, 1:256 prescale, Fosc/2
    PR1 = F_CY/256/freq_hz;
}

void tmr2_init(u16 freq_hz)
{
    T2CON = 0b1000000000110000; // TMR2 on, 1:256 prescale, 2x indept 16-bit, Fosc/2
    PR2 = F_CY/256/freq_hz;
}

void irq_init(void)
{
    _AD1IF = 0; // ADC1 Event Interrupt Flag
    _AD1IP = 1; // lowest priority level
    _AD1IE = ENABLE; // ADC1 Event Interrupt Enable

    _T2IF = 0; // Timer1 Flag
    _T2IP = 1; // lowest priority level
    _T2IE = ENABLE; // timer1 interrupt enable

    _T1IF = 0; // Timer1 Flag
    _T1IP = 3; // third lowest priority level
    _T1IE = ENABLE; // timer1 interrupt enable

    _CNIF = 0; // ChangeNotification Flag
    _CNIP = 4; // highest priority level
    _CNIE = ENABLE; // change notification interrupt enable
}

//==============================================================================
//--------------------MODULE CAN PROCESS----------------------------------------
//==============================================================================
void module_ecanrx(u8 idx, u16 pid, u16 *data, u8 msg_type, u8 flags, u8 len)
{
    u8 i;
    u8* dptr = (u8*)data;
    if (idx) return; // expect idx==0 for MODULE

    // Get Name
    if ((msg_type==MT_REMOTE_CMD)&&(dptr[2]==RC_GET_NAME)&&(flags==0)&&(len==3)) {
        if (data[0]==DPI_ALL_MODULES) // send this module name
            ecan_tx_str(settings.param[0].pid, (char*)settings.param[0].name, MT_BROADCAST_NAME, 8);

        if ((data[0]==DPI_ALL_PARAMETERS)||(data[0]==settings.param[0].pid)) // all parameters, or all parameters of this module
            for (i=1;i<PARAM_CNT;i++) // send all parameter ID names of this module
                ecan_tx_str(settings.param[i].pid, (char*)settings.param[i].name, MT_BROADCAST_NAME, 8);

        for (i=1;i<PARAM_CNT;i++)
            if (data[0]==settings.param[i].pid)
                ecan_tx_str(settings.param[i].pid, (char*)settings.param[i].name, MT_BROADCAST_NAME, 8);
    }
    if ((msg_type==MT_BROADCAST_NAME)&&(flags==ECAN_FLAGS_RTR)&&(len==0)) {
        for (i=0;i<PARAM_CNT;i++)
            if (data[0]==settings.param[i].pid)
                ecan_tx_str(settings.param[i].pid, (char*)settings.param[i].name, MT_BROADCAST_NAME, 8);
    }

    // Get Value
    if ( ((msg_type==MT_REMOTE_CMD)&&(dptr[2]==RC_GET_VALUE)&&(flags==0)&&(len==3)) ||
       ((msg_type==MT_BROADCAST_VALUE)&&(flags==ECAN_FLAGS_RTR)&&(len==0)) ) {
        for (i=1;i<PARAM_CNT;i++)
            if ((data[0]==settings.param[i].pid)&&(PARAM_CONST[i].sendval_fnc_ptr))
                PARAM_CONST[i].sendval_fnc_ptr(i);
    }

    // Remote Menu / Terminal Console
    if ((msg_type==MT_REMOTE_CMD)&&(dptr[2]==RC_CONSOLE_KEY)&&(flags==0)&&(len==4)) {
        for (i=0;i<PARAM_CNT;i++)
            if (data[0]==settings.param[i].pid) {
                static u8 current_menu_idx = 255;
                if ((current_menu_fnc==0)||(current_menu_idx!=i)) { // if not in sub-menu of previous
                    tmp_settings = settings; // copy settings for modifying
                    current_menu_fnc = PARAM_CONST[i].menu_fnc_ptr;
                }
                if (current_menu_fnc) // call console function
                    current_menu_fnc = (*current_menu_fnc)(i,dptr[3]);
                if (current_menu_fnc==0) // send EXIT if invalid or response==0
                    ecan_tx_console(settings.param[i].pid, 0);
                current_menu_idx = i;
                break;
            }
    }
}

//==============================================================================
//--------------------MAIN LOOP-------------------------------------------------
//==============================================================================
int main(void)
{
    u8 i;
    OSCTUN = 11; // 7.408 MHz
    CLKDIV = 0; // N1=2, N2=2
    PLLFBD = 52; // M=54
    // Fosc = 7.408*M/(N1*N2) = 100.00938915 MHz
    // Fcy  = Fosc/2 = 50.004695 MIPS
    while (OSCCONbits.LOCK!=1){}; // Wait for PLL to lock

    // Call Parameter Init functions
    iopins_init();
    ecan_init();
    analog_init();
    i2c_init();
    bmp180_init(BMP180_ULTRALOWPOWER);
    mpu6050_init();
    hmc5883_init();
    thermocouple_init();
    fuelflow_init();
    rpm_init();
    tmr1_init(50); // 50 Hz == 20 ms ticks
    tmr2_init(1000); // 1000 Hz == 1 ms ticks
    irq_init();
    
    while(1)
    {
        // handle CAN receive messages here
        ecan_process();

        // process pressure sensor readings
        bmp180_process();

        // handle TMR timeout function calls here
        for (i=1;i<PARAM_CNT;i++)
            if ((rate_cnt[i]==0)&&(settings.param[i].rate)) {
                if (PARAM_CONST[i].sendval_fnc_ptr) // if timeout fnc exists
                    PARAM_CONST[i].sendval_fnc_ptr(i);
                rate_cnt[i] = settings.param[i].rate; // reload countdown value
            }
    }
}

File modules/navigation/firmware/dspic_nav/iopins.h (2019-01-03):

#ifndef RELAY_H
#define RELAY_H

#include "common.h"

#define LED1t                       TRISBbits.TRISB15
#define LED1                        LATBbits.LATB15

#define RELAY1t                     TRISAbits.TRISA3
#define RELAY1                      LATAbits.LATA3

#define OPENDRAIN1t                 TRISBbits.TRISB13
#define OPENDRAIN1                  LATBbits.LATB13
#define OPENDRAIN2t                 TRISAbits.TRISA4
#define OPENDRAIN2                  LATAbits.LATA4

void iopins_init(void);
void led_toggle(void);
void iopins_ecanrx(u8 idx, u16 pid, u16 *data, u8 msg_type, u8 flags, u8 len);
void iopins_sendrelay(u8 idx);
void iopins_sendod1(u8 idx);
void iopins_sendod2(u8 idx);
void* iopins_relay_menu(u8 idx, u8 key_input);
void* iopins_od1_menu(u8 idx, u8 key_input);
void* iopins_od2_menu(u8 idx, u8 key_input);
void iopins_printmenu(u8 idx, u8 state);

#endif

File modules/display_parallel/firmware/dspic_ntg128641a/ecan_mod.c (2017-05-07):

#include "ecan_mod.h"

__attribute__((aligned(NR_ECAN_BUF*16))) u16 ecan_buf[NR_ECAN_BUF][8];

extern void ecan_rx(u16 pid, u16 *data, u8 msg_type, u8 flags, u8 len);

void ecan_irq(void)
{
    u8 buf_sel = C1VECbits.ICODE;
    if (ecan_buf[buf_sel][0] & 0x0001) { // Extended Identifier (29-bit ID)
        // CID = CAN-ID = 0b000s.ssss.ssss.ssee.eeee.eeee.eeee.eeee
        // where s [bit28:18] = SID (11 bit)
        //       e [bit17:00] = EID (18 bit)
        u8 msg_type = (ecan_buf[buf_sel][0] & 0x03FC) >> 2;
        u8 len = ecan_buf[buf_sel][2]&0x000F; // Data Length Code
        u16 pid = (ecan_buf[buf_sel][2]&0xF000) >> 12;
        pid |= ecan_buf[buf_sel][1] << 4;
        u8 flags = (ecan_buf[buf_sel][2] & 0x0C00) >> 10;
        if (ecan_buf[buf_sel][2] & 0x0200) // remote frame request
            flags |= ECAN_FLAGS_RTR;
        ecan_rx(pid, &ecan_buf[buf_sel][3], msg_type, flags, len);
    }
    C1RXFUL1 = 0xFFFF ^ (1<<buf_sel); // Clear Rx Buffer Full Flag
    C1INTFbits.TBIF = 0; // Clear TX Buffer Interrupt Flag
    C1INTFbits.RBIF = 0; // Clear RX Buffer Interrupt Flag
}

void ecan_tx(u16 pid, u16 d0, u16 d2, u16 d4, u16 d6, u8 msg_type, u8 flags, u8 len)
{
    while (_TXREQ0) ; // wait for first transmit buffer to become available
    // Always transmit using Extended Identifier format
    ecan_buf[0][0] = (msg_type<<2) | 0b11;
    ecan_buf[0][1] = (pid&0xFFF0)>>4;
    ecan_buf[0][2] = ((pid&0x000F)<<12) | ((flags&0x3)<<10) | ((flags&ECAN_FLAGS_RTR)?0x200:0) | len;
    ecan_buf[0][3] = d0; // byte 0 and 1
    ecan_buf[0][4] = d2; // byte 2 and 3
    ecan_buf[0][5] = d4; // byte 4 and 5
    ecan_buf[0][6] = d6; // byte 6 and 7
    _TXREQ0=1;
}

void ecan_init(void)
{
    // I/O Pin direction, mode, and re-mapping (PPS)
    U1RXt = INPUT_PIN;
    U1TX = 1; // recessive state by default
    U1TXt = OUTPUT_PIN;
    U1RXa = DIGITAL_PIN;
    _RP39R = 14; // CAN_TXD (output) RB7 == RP39 <- C1TX (TABLE 11-3 in DS70000657H)
    _C1RXR = 40; // CAN_RXD (input)  RB8 == RP40 -> C1RX (TABLE 11-2 in DS70000657H)

    C1CTRL1bits.REQOP = 0b100; // enter config mode
    while(C1CTRL1bits.OPMODE != 0b100); // wait for config mode

    // Memory Map Select (0 or 1: C1CTRLx,C1VEC,C1FCTRL,C1FIFO,C1INTF,C1INTE,C1EC,C1CFGx,C1FEN1,C1FMSKSELx)

    // Set Bit Timing to 1 Mbps
    // N = 20 time quanta per bit;   FTQ = N x baud = 20 MHz
    C1CTRL1bits.CANCKS = 1; // FCAN is equal to 2*FP (==2*F_CY)
    C1CFG2bits.SEG1PH = 0x7; // Phase Segment 1 time is 8 TQ
    C1CFG2bits.SEG2PHTS = 0x1; // Phase Segment 2 time is set to be programmable
    C1CFG2bits.SEG2PH = 0x5; // Phase Segment 2 time is 6 TQ
    C1CFG2bits.PRSEG = 0x4; // Propagation Segment time is 5 TQ
    C1CFG2bits.SAM = 0x1; // Bus line is sampled three times at the sample point
    C1CFG1bits.SJW = 0x3; // Synchronization Jump Width set to 4 TQ
    C1CFG1bits.BRP = 0x2; // Baud Rate Prescaler = FCAN /(2*FTQ) -1

    // Memory Map Select (1: C1BUFPNTx,C1RXMxSID,C1RXMxEID,C1RXFxSID,C1RXFxEID)
    C1CTRL1bits.WIN = 1;

    // Configure Receive Buffers [buffers 8 to 15]
    C1FCTRLbits.DMABS = 0b100; // 16 buffers in device RAM
    C1FCTRLbits.FSA = 8; // FIFO starts at buffer 8 (rx buffers)
    C1RXF0SIDbits.SID = 0; // configure filter 0
    C1RXF0SIDbits.EXIDE = 1; // extended identifier address
    C1RXF0SIDbits.EID = 0;
	C1RXF0EIDbits.EID = 0;
    C1BUFPNT1bits.F0BP = 0b1111; // assign filter 0 to FIFO
    C1RXM0SIDbits.SID = 0; // configure mask 0 (all bits are ignored in filter comparison)
    C1RXM0EIDbits.EID = 0;
    C1FMSKSEL1bits.F0MSK = 0; // select mask 0 for filter 0
	C1FEN1 = 0x1; // enable filter 0

    // Memory Map Select (0: C1RXFULx,C1RXOVFx,C1TRxxCON,C1RXD,C1TXD)
    C1CTRL1bits.WIN = 0;

    // Configure Transmit Buffers [buffers 0 to 7]
    C1TR01CONbits.TXEN0 = ENABLE; // buffers are transmit buffers
    C1TR01CONbits.TXEN1 = ENABLE;
    C1TR23CONbits.TXEN2 = ENABLE;
    C1TR23CONbits.TXEN3 = ENABLE;
    C1TR45CONbits.TXEN4 = ENABLE;
    C1TR45CONbits.TXEN5 = ENABLE;
    C1TR67CONbits.TXEN6 = ENABLE;
    C1TR67CONbits.TXEN7 = ENABLE;

    // Setup DMA0 for TX_RAM -> CAN_TX
    DMA0CONbits.SIZE = 0x0; // word instead of byte
    DMA0CONbits.DIR = 0x1; // read from RAM address, write to peripheral address
    DMA0CONbits.AMODE = 0x2; // Peripheral Indirect Addressing mode
    DMA0CONbits.MODE = 0x0; // Continuous, Ping-Pong modes disabled
    DMA0REQ = 70; // DMA Peripheral IRQ Number Select: ECAN1 ? TX Data Request
    DMA0CNT = 7;
    DMA0PAD = (volatile u16)&C1TXD;
    DMA0STAL = (u16)&ecan_buf[0][0];
    DMA0STAH = (u16)&ecan_buf[0][0];
    DMA0CONbits.CHEN = ENABLE;

    // Setup DMA1 for CAN_RX -> RX_RAM
    DMA1CONbits.SIZE = 0x0; // word instead of byte
    DMA1CONbits.DIR = 0x0; // Read from Peripheral address, write to RAM address
    DMA1CONbits.AMODE = 0x2; // Peripheral Indirect Addressing mode
    DMA1CONbits.MODE = 0x0; // Continuous, Ping-Pong modes disabled
    DMA1REQ = 34; // DMA Peripheral IRQ Number Select: ECAN1 ? RX Data Ready
    DMA1CNT = 7;
    DMA1PAD = (volatile u16)&C1RXD;
    DMA1STAL = (u16)&ecan_buf[0][0];
    DMA1STAH = (u16)&ecan_buf[0][0];
    DMA1CONbits.CHEN = ENABLE;

    C1CTRL1bits.REQOP = 0; // enter normal mode
    while(C1CTRL1bits.OPMODE != 0); // wait for normal mode

    C1INTEbits.RBIE = ENABLE; // Receive Buffer Interrupt Enable
}

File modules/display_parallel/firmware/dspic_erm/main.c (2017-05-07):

#include "xc.h"
#include <stdio.h>
#include <stdlib.h>
#include <string.h>
#include "common.h"
#include "config_bits.h"
#include "led.h"
#include "buzzer.h"
#include "rot_enc.h"
#include "glcd.h"
#include "glcd_lib.h"
#include "ecan_mod.h"
#include "widgets.h"
#include "menu_functions.h"
#include "modair_bus.h"
#include "heap.h"

//==============================================================================
//--------------------GLOBAL VARIABLES------------------------------------------
//==============================================================================
volatile __attribute__((far)) u16 heap_mem[HEAP_MEM_SIZE];
volatile u8 heap_item_cnt = 0;
volatile u8 heap_alloc = 0;

volatile s_pid_val pid_vals[64];
volatile u16 pid_vals_cnt = 0;

volatile u8 rot_enc_input = 0;

// use function pointers to navigate through the menu;
// default screen after bootup: home screen
void* (*current_menu_fnc)(u8) = &menu_fnc_homescreen;


//==============================================================================
//--------------------INTERRUPTS------------------------------------------------
//==============================================================================
void __attribute__((interrupt, auto_psv)) _T1Interrupt(void)
{
    rot_enc_tmr();
    _T1IF = 0;  // clear the interrupt
}

void __attribute__((interrupt, auto_psv)) _CNInterrupt(void)
{
    rot_enc_irq();
    _CNIF = 0;  // clear the interrupt
}

void __attribute__((interrupt, auto_psv)) _C1Interrupt(void)
{
    ecan_irq();
    _C1IF = 0;  // clear the interrupt
}

//==============================================================================
//--------------------INIT FUNCTIONS--------------------------------------------
//==============================================================================
void osc_init(void)
{
    OSCTUN = 0; // 7.37 MHz
    CLKDIV = 0; // N1=2, N2=2
    PLLFBD = 63; // M=65
    // Fosc = 7.37*M/(N1*N2) = 119.7625 MHz
    // Fcy  = Fosc/2 = 59.88125 MIPS
    while (OSCCONbits.LOCK!=1){}; // Wait for PLL to lock
}

void tmr1_init(u16 freq_hz)
{
    T1CON = 0b1000000000110000; // TMR1 on, 1:256 prescale, Fosc/2
    PR1 = F_CY/256/freq_hz;
}

void irq_init(void)
{
    _T1IF = 0; // Timer1 Flag
    _T1IP = 2; // second lowest priority level
    _T1IE = ENABLE; // timer1 interrupt enable

    _CNIF = 0; // ChangeNotification Flag
    _CNIP = 1; // lowest priority level
    _CNIE = ENABLE; // change notification interrupt enable

    _C1IF = 0; // CAN1 Event Interrupt Flag
    _C1IP = 3; // third lowest priority
    _C1IE = ENABLE; // CAN1 Event Interrupt Enable
}

//==============================================================================
//--------------------COMMUNICATIONS HANDLER------------------------------------
//==============================================================================
void ecan_rx(u16 pid, u16 *data, u8 msg_type, u8 flags, u8 len)
{
    if ((heap_alloc==HEAP_ALLOC_CANDEBUG)&&(heap_item_cnt<8)) { // Debug-Bus menu is active
        s_can_debug* can_dbgs = (s_can_debug*)&heap_mem[0];
        can_dbgs[heap_item_cnt].pid = pid;
        can_dbgs[heap_item_cnt].d0 = data[0];
        can_dbgs[heap_item_cnt].d2 = data[1];
        can_dbgs[heap_item_cnt].d4 = data[2];
        can_dbgs[heap_item_cnt].d6 = data[3];
        can_dbgs[heap_item_cnt].msg_type = msg_type;
        can_dbgs[heap_item_cnt].len = len;
        can_dbgs[heap_item_cnt].flags = flags;
        heap_item_cnt++;
    }

    switch (msg_type) {
        case MT_BROADCAST_VALUE: {
                float *val = (float*)data;
                u16 i;
                for (i=0;i<pid_vals_cnt;i++)
                if (pid_vals[i].pid == pid) {
                    pid_vals[i].val = *val;
                    break;
                }
            }
            break;
        case MT_BROADCAST_NAME:
            if ((heap_alloc==HEAP_ALLOC_PIDNAME)&&(heap_item_cnt<MAX_PID_NAME_ITEMS)&&(flags==FT_PKT_SINGLE)) {
                s_pid_name* pid_names = (s_pid_name*)&heap_mem[0];
                pid_names[heap_item_cnt].pid = pid;
                pid_names[heap_item_cnt].u.nval[0] = data[0];
                pid_names[heap_item_cnt].u.nval[1] = data[1];
                pid_names[heap_item_cnt].u.nval[2] = data[2];
                pid_names[heap_item_cnt].u.nval[3] = data[3];
                if (len<8) // terminate string
                    pid_names[heap_item_cnt].u.name[len] = 0x00;
                heap_item_cnt++;
            }
            break;
        case MT_CONSOLE_TEXT:
            if (heap_alloc==HEAP_ALLOC_CONSOLETXT) {
                s_console_txt* console_txt = (s_console_txt*)&heap_mem[0];
                if (console_txt->pid == pid) {
                    if ((flags==FT_PKT_START)||(flags==FT_PKT_SINGLE)) {
                        memset((char*)console_txt->txt, ' ', 16*4);
                        heap_item_cnt=0;
                    }
                    if (heap_item_cnt<8) {
                        memcpy((char*)&console_txt->txt[heap_item_cnt*8], (char*)&data[0], len);
                        heap_item_cnt++;
                    }
                }
            }
            break;
    }
}



//==============================================================================
//--------------------MAIN LOOP-------------------------------------------------
//==============================================================================
int main(void)
{
    osc_init();
    led_init();
    buzzer_init();
    rot_enc_init();
    lcd_init();
    ecan_init();
    tmr1_init(50); // 50 Hz == 20 ms ticks
    irq_init();

    read_widgets();

    while(1) {
        // clear lcd-buffer
        lcd_clrbuff();

        // latch input from rotary-encoder (changed during IRQs)
        u8 rot_enc_input_b = rot_enc_input;
        rot_enc_input = 0;

        // extra-long-press always gets you back to home-screen
        if ((rot_enc_input_b == C_ROT_EXTRALONGHOLD) || (current_menu_fnc == NULL)) {
            current_menu_fnc = &menu_fnc_homescreen;
            heap_alloc = HEAP_ALLOC_NONE; // deallocate heap
            rot_enc_input_b = 0;
        }

        // call current menu-function and update next menu-function pointer
        current_menu_fnc = (*current_menu_fnc)(rot_enc_input_b);

        // copy lcd-buffer to lcd
        lcd_update();
        led_toggle();
    }
}
//==============================================================================
//==============================================================================

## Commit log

2017-03-26 First manufacturing batch
    Hardware:
    Parallel Transflective LCD Modules: 16x2, 128x64, 256x64.
    Rotax Engine Interface Module.
    Firmware:
    Initial test code for all components
    [disp.brd, disp.sch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]
2017-04-04 Nelytech GLCD Initial Test
    Printed pixels to screen... still need to write efficient buffer copy
    function
2017-04-08 changed rotary encoder input to be compatible with ASCII
    future plan: allow remote menu or keyboard input
2017-04-12 added schematic pdf
2017-04-23 Added ModAirBus defines, CAD 3D brackets for LCD mounting
    [erm25664_bracket.SLDPRT, erm25664_bracket.STL, erm25664_frontpanel.DXF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]
2017-04-23 reverted main branch back to non-rotated lcd
    new branch now has 90 degree rotated version
    [glcd.h]
2017-04-28 added a bunch of parameters to the engine module
    [ntc_table.xlsx]
2017-04-29 added menu_fnc_ptr to the PARAM_CONST structure, and handle remote console function calls from main.c... this greatly simplifies parameter.c
    [bom.csv]
2017-04-30 added block diagrams, added engine_rotax RTR response
    [bom.csv]
2017-05-13 pressure sensor interface to gy87 working
2017-05-13 gy87 compass and gyro/acc interfaces working
2018-09-27 work in progress on the navigation module to fit the Hammond enclosure
    [bom.csv, nav.brd, nav.sch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]
2018-09-27 ERC240160 3D printed enclosure (initial FDM version)
    [ERC240160_ENCLOSURE.SLDDRW, ERC240160_ENCLOSURE.SLDPRT, ERC240160_ENCLOSURE.STL]
2018-10-14 initial FPC LCD hardware with DC-DC converter module
    [fpc.brd, fpc.sch]
2018-12-29 discrepancy between 16-Bit_Language_Tools_Libraries_Manual.pdf and the flash_helper.s source file:
    _write_flash16 does not seem to work, and _write_flash_word32 works (even though the docs say it's currently disabled)
2019-01-03 added calibration menu for fuel_level,
    merged IO pins to single C/H file and added menus.
2019-01-05 changed Fcy to 50 MIPS to avoid Fclk overlap with VHF radio airband
    [common.h, ecan_mod.c, main.c]

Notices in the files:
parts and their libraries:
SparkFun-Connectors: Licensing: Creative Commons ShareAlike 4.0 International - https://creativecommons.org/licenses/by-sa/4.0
